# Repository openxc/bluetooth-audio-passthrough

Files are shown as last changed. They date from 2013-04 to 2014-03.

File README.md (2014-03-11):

Bluetooth Audio Accessory
=========================

This repository is a part of the [OpenXC][] project.

This repository contains the documentation and open source design files for an
example OpenXC hardware accessory, the Bluetooth Audio accessory, originally
created by Ford.

There is a [gallery of
photos](https://plus.google.com/photos/108408483770573977605/albums/5989364910333751905)
of the prototype accessory.

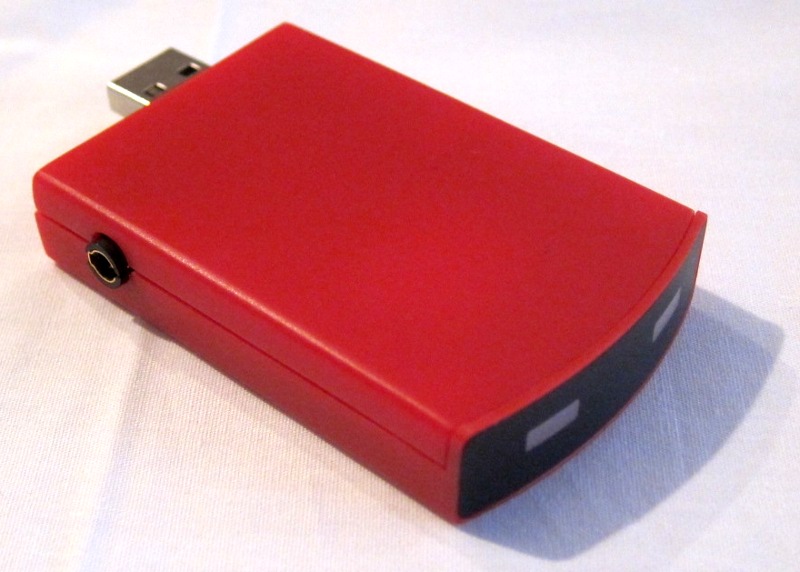
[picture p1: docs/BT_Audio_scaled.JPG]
Bluetooth Audio Accessory The Bluetooth Audio Accessory


### Description

The Bluetooth Audio Passthrough is an audio-capable Bluetooth chipset, powered
and configurable over USB. The Passthrough uses a Bluegiga WT-32 Bluetooth
module, which is capable of running several different Bluetooth profiles in the
Bluetooth 2.1 standard (and even multiple profiles in parallel). By default, the
BT Passthrough will appear as an A2DP audio sink - an audio endpoint that can
wirelessly stream audio from a cellphone music player to a car Aux input.

### Features

* Supports many Bluetooth protocols out of the box: SPP, DUN, OBEX OPP, HFP
    (v.1.5) A2DP, AVRCP, DID and HID
* Configurable over USB using easy-to-read commands
* 2 output channels (stereo), one input channel (mono)
* Provides a 2.7v microphone bias
* Output headphone amplifier capable of driving up to 105mW per channel

Documents
---------

The schematics, board layout, BOM and testing results are in the `schematics`
directory of this repository.

The schematics were created with Eagle, and are also available as PNGs.

### Assembly Files

The assembly files are in the `fabrication` subfolder, including the board
layout DXF and and archive of all assembly files:

 * .top  - Top Copper Layer
 * .bot  - Bottom Copper Layer
 * .smt - Top Soldermask
 * .slk - Top Silkscreen
 * .tsp - Top Solderpaste
 * .smb - Bottom Soldermask
 * .bsk - Bottom Silkscreen
 * .bsp - Bottom Solderpaste
 * .oln - PCB Outline
 * .drd - Excellon Drill Data
 * .drl - Basic Drill tool information
 * .dri - Extended Drill tool information

Details
-------

### Block diagram

Bluetooth Audio Block Diagram

### Parts Layout

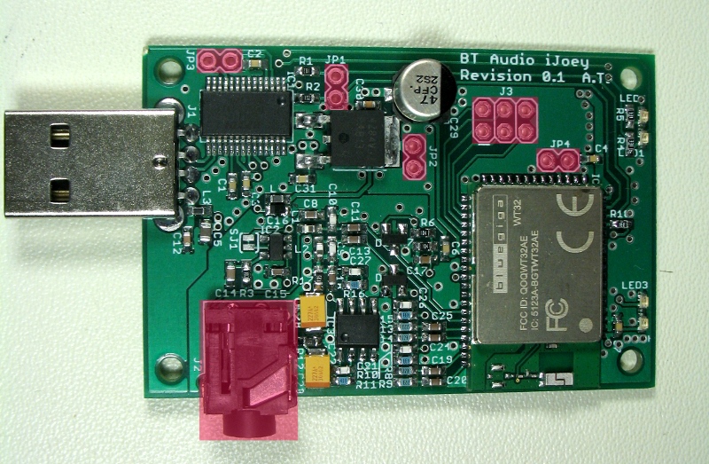
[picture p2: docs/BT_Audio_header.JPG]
Bluetooth Audio Headers


### Inputs/Outputs

* JP1 - Serial RX and TX lines - if the USB-Serial interface is not working,
    the TX and RX serial lines can be accessed from this header.
* JP2 - Power - Access to the +3.3V and Ground power rails.
* JP3 - USB CTS and RTS - Access to the hardware flow control lines provided
    by the FT232RL USB to serial IC.
* JP4 - Bluetooth CTS and RTS - Access to the hardware flow control lines on
    the WT32 adapter. Can be used with JP3 to enable hardware flow control.
* J3 - SPI programming interface - If the firmware on the WT32 needs to be
    updated from iWrap 4, this interface can be used.
* J2 (the Headphone Jack) - This is a 4 pole TRRS connector, which can be used
    for 2 output channels and 1 input channel. A standard 3-pin TRS headphone
    cable can be used, and the microphone input will be unused.
    * Pin 1 (tip) - Out Left
    * Pin 2 (ring 1) - Out Right
    * Pin 3 (ring 2) - Ground
    * Pin 4 (shield) - Microphone Input

Usage:
------

### How to use

1. Plug the Bluetooth Audio Accessory into the Dock
1. Connect the short 4-pin 1/8" TRRS cable to the audio jack on the Accessory
1. Connect the other end of the TRRS cable into the dock
1. Plug a 1/8" headset or 1/8" extension cable into the dock
1. On a smartphone or tablet, search for Bluetooth devices
1.  A "WT-32" device should appear. Pair with it. No PIN code should be
    necessary, but "0000" can be used.
1.  Once pairing is complete, connect to the WT-32 device
1. The LED on the Bluetooth Audio Accessory should turn green and the Bluetooth
    host should now play audio through the device.

### How to program

Upon receiving a Bluetooth Audio Accessory from the factory, a quick
configuration step will be required:

1. Connect the Accessory directly into the USB port of a PC
1. The accessory should appear as a serial device (/dev/ttyUSBX in linux, COMX
   in windows, /dev/tty.usbserial-xxxxxxxx in OSX).
1. In a terminal application, open the serial port with baud 115200 and no
   hardware flow control.
1. Type ```RESET``` and press enter. The Accessory should respond with the
   iWrap firmware version.
1. Type the following commands, pressing enter after each line:

```
SET BT SSP 3 0
SET BT AUTH * 0000
SET PROFILE A2DP SINK
SET PROFILE AVRCP CONTROLLER
SET BT CLASS 240438
SET CONTROL GAIN D D
SET CONTROL INIT SET CONTROL GAIN D D
SET CONTROL CD 400 0
RESET
```

The device should now be ready for use as an A2DP sink. Here are a few other
popular protocols (repeat the above steps to apply):

#### A2DP Sink (Audio from Bluetooth to Speaker)

```
SET PROFILE A2DP SINK

SET PROFILE AVRCP CONTROLLER

SET BT CLASS 240438
```

#### A2DP Source (Audio from Microphone to Bluetooth)

```
SET PROFILE A2DP SOURCE

SET PROFILE AVRCP TARGET

SET BT CLASS 280428
```

#### HFP - Hands Free Protocol (Act like Bluetooth Headset)

```
SET BT SSP 3 0
SET BT AUTH * 0000
SET PROFILE HFP ON
SET BT CLASS 200404
```

### Known issues

#### v0.1

* Audio output noise
    * Power supply - The audio output is fairly sensitive to power supply
        noise. The +5V USB power supply is filtered, but very noisy USB busses
        can still produce audible pops and buzzes
    * Bluetooth - The headphone amplifier is somewhat sensitive to Bluetooth
        energy. If the connected tablet or cell phone is held very closely to
        the BT Passthrough, cellular and/or Bluetooth noise will be induced into the
        audio output. Try not to rest any cellular devices immediately against
        the Passthrough.
* Audio output level - The default gain on the WT32 chipset is fairly
    conservative. To increase the default gain, connect the BT Passthrough to a PC. It
    should appear as a serial device. Connect to that serial device at 115200
    baud, and send the following commands:

```
RESET

SET CONTROL GAIN D D

SET CONTROL INIT SET CONTROL GAIN D D

RESET
```

Try adjusting the 0xD parameter above (valid range is 0 - 17 in hexadecimal, see
the WT-32 manual). In testing, a gain of 0xD is the highest that a pair of 64
ohm headphones would tolerate before distortion.

Design details:
---------------

### Bluetooth Chipset

The WT-32 was selected as a prototype-friendly Bluetooth Audio chipset. It was
the only chipset available from distributors like SparkFun that had full, native
audio support. Advantages:

* Simple serial command protocol
* Many built-in Bluetooth protocols
* Built-in microphone pre-amplifier with software-adjustable gain
* software-adjustable output gain as well

The basic WT-32 design is very strongly based from its [Evaluation
Board](http://www.digikey.com/product-search/en/rf-if-and-rfid/rf-evaluation-and-development-kits-boards/3539644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).
The WT32 documentation is available in the Documentation directory.

### Configuration Interface

The WT-32 is configured by a serial UART at 115200 baud. This is exposed via
USB using an industry-standard [FTDI
FT232RL](http://www.ftdichip.com/Support/Documents/DataSheets/ICs/DS_FT232R.pdf)
USB to serial converter IC. The chip requires few external components - each
power rail is decoupled with 0.1uF capacitors, TX and RX LEDs are included, and
the UART is protected from excess current through RX and TX resistors R1 and R2.
USB signals require high speed PCB routing to avoid signal integrity issues,
since the bitrates are high (11Mbps - 480Mbps). Unfortunately with a 2 layer
PCB, the trace widths required to obtain the ideal 90 ohm differential impedance
for a USB line would be unfeasibly wide. To compensate for this fact, the USB
connector was located extremely close (~300 mils) to the FTDI 232RL USB pins.

The WT-32 also has an ICSP header if future firmware updates are desired.
Current WT-32 modules will ship with either iWrap4 or iWrap5 firmware, both of
which contain the necessary configurations and protocols needed by the
accessory. Upgrading shouldn't be necessary, but is possible using the SPI bus
exposed by J3. See the WT32 documentation for firmware upgrade procedures.

### Power

A single Low Dropout linear regulator is used to step the +5V USB power down to
the 3.3V required by the Bluetooth module. IC5 preforms this task, providing up
to 1.6A of current (far more than is necessary). The power is filtered in two
places. Immediately after entering via the USB connector, power is passed
through inductor L3 with filtering capacitors C12 and C5. This is from the
FT232RL reference design. An additional filtering stage separates the normal
+3.3V rail from the +3.3V used by the analog audio circuitry. Analog power is
run through inductor L4 and decoupled by C16 in an attempt to remove additional
transients caused by the power draw of the WT32.

A DC midpoint is also required by the output amplifier. Since the amplifier is
a single-ended device (no negative power rail is available), a midpoint is
required to properly bias / center the audio signal before amplification. This
is generated using a rudimentary resistor divider of R6 and R7. Excess DC
midpoint current can unbalance the amplifier, but with the low input impedance
of the output amplifier, this shouldn't be an issue. If the DC midpoint becomes
unbalanced, or if more ground filtering is desired, consider buffering the
DC_MID signal with an opamp.

### Analog Microphone Input

The microphone input receives it's signal from pin 4 of the TRRS audio
connector. IC2 provides a 2.7V microphone bias for the microphone in a
connected headset. The WT32 contains a microphone bias output, but the
reference schematic recommends using an additional Low Dropout Regulator (IC2)
instead. The LDO provides additional power filtering for the microphone bias,
which is an extremely noise-sensitive signal for an electret microphone element.
This circuit assumes a microphone element with an impedance in the 1k - 3k range
(specifically we are matching 1K using resistor R3).

Inductors L1 and L2 and capacitors C9 and C10 attempt to filter excess high
frequency noise from the microphone. Capacitors C11 and C13 decouple the
microphone signal before connecting it to the WT32. Diodes D1 and D2 protect
the WT-32 built-in microphone preamplifier and ADC from damage due to voltage
transients by clamping the microphone signal to +3.3v and Ground. Note that
this circuit uses a shared ground for the microphone input and the headphone
output - if crosstalk between headphones and microphone becomes an issue,
consider spliting the 4-pin TRRS jack into two seperate 3-pin TRS jacks.

### Headphone / Line output

A [TI LM4808 Headphone Amplifier](http://www.ti.com/lit/ds/symlink/lm4808.pdf)
isolates the audio output from the WT32. The reference design was pulled
directly from the WT-32 evaluation board. The amplifier also converts the
differential audio output of the WT32 into a single-ended output used by most
headphones and consumer electronics. Note that output decoupling capacitors C23
and C28 are specified as Tantalum capacitors, since they lie directly in the
audio pathway and need to be robust to handle the voltage transients of plugging
and unplugging audio signals. Care must be taken to chose capacitors with a
good sonic signature, low ESR and a sufficient voltage rating.

## License

Copyright (c) 2014 Ford Motor Company

The electrical and mechanical designs in this repository are available under the
[Creative Commons Attribution 4.0
International](http://creativecommons.org/licenses/by/4.0/deed.en_US) license.

[OpenXC]: http://openxcplatform.com

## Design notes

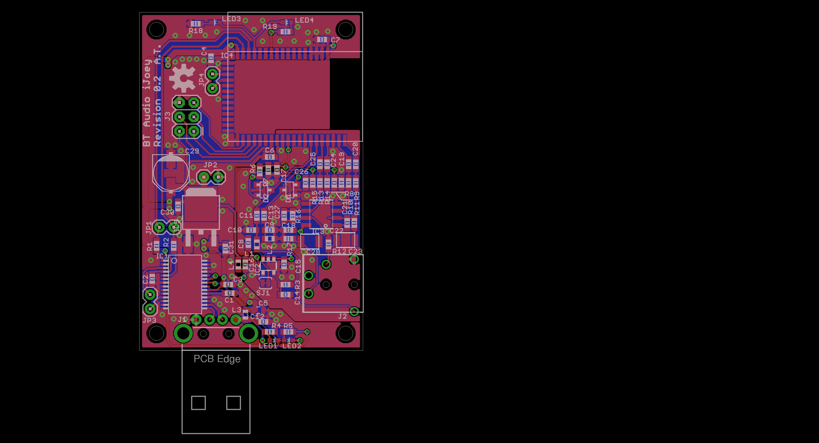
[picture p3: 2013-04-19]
schematics/BT_Audio_iJoey.brd.png

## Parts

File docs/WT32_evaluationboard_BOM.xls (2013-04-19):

WT32 Evaluation Kit
BOM ver. 2.6, 31.03.2011
Bluegiga Technologies Oy
Author: Pra
Item | Qty | Reference | Value | Description | ROHS PN=Orderable PN | Distributor | Distributor PN | Mounted | Manufacturer | Second source | Second source PN | Package
1 | 4 | DIO1-4 |  | Schottky diode | BAT54S |  |  | TRUE | FAIRCHILD
2 | 6 | SW4 SW6-10 |  | Switch button | KSC423J |  |  | TRUE | C & K
3 | 20 | C14-20 C23-24 C40-46 C51-54 | 0.1uF/25V/X7R | General Ceramic Chip Capacitor | GRM188R71E104KA01 | Elgood |  | TRUE | Murata |  |  | 603
4 | 4 | C25 C50 C55-56 | 0.22uF/6.3V/X5R | General Ceramic Chip Capacitor | GRM155R60J224KE01 | Elgood |  | TRUE | Murata |  |  | 402
5 | 1 | C29 | 1000pF/50V/X7R | General Ceramic Chip Capacitor | GRM155R71H102KA01 | Elgood |  | TRUE | Murata |  |  | 402
6 | 1 | C10 | 10uF/6.3V/Y5V | Monolithic Ceramic Chip Capacitor | GRM21BF50J106ZE01K | Elgood |  | TRUE | Murata |  |  | 805
7 | 1 | C28 | 10uF/16V/10%/TAN | Tantalum Capacitor | T491A106K016AT | Arrow/Farnell | 1310077 | TRUE | Kemet |  |  | CASE-A
8 | 1 | C49 | NP | General Ceramic Chip Capacitor | NP |  |  | FALSE
9 | 6 | C5-8 C11 C48 | 15pF/50V/C0G | High Q Low ESR Ceramic Chip Capacitor | GJM1555C1H150JB01 | Elgood |  | TRUE | Murata |  |  | 402
10 | 12 | C1-4 C9 C26-27 C30-33 C38 | 1uF/16V/X5R | General Ceramic Chip Capacitor | GRM188R61C105KA93 | Elgood |  | TRUE | Murata |  |  | 603
11 | 2 | C12-13 | 220uF/10V/10%/TAN | Tantalum Capacitor | T491D227K010AT | Arrow/Farnell | 1310127 | TRUE | Kemet |  |  | CASE-D
12 | 1 | C22 | 22uF/16V/10%/TAN | Tantalum Capacitor | T491B226K016AT | Arrow/Farnell | 1308258 | TRUE | Kemet |  |  | CASE-B
13 | 2 | C21 C39 | 2.2uF/10V/X5R | General Ceramic Chip Capacitor | GRM188R61A225KE34 | Elgood |  | TRUE | Murata
14 | 4 | C34-37 | 33pF/50V/C0G | General Ceramic Chip Capacitor | GRM1555C1H330JZ01 | Elgood |  | TRUE | Murata
15 | 1 | C47 | 4u7 | General Ceramic Chip Capacitor | GRM188R60J475KE19 | Elgood |  | TRUE | Murata |  |  | 603
16 | 1 | J10 |  | Mini-USB connector, socket, SMD | 2486 01 | Farnell | 1243250 | TRUE | Lumberg
17 | 3 | FID1-3 | Fiducial Mark 1mm , 2mm keep out | Fiducial Mark 1mm , 2mm keep out | N/A | N/A | N/A | FALSE | N/A | N/A | N/A
18 | 3 | J11-13 |  | TWO PIN INLINE HEADER; 100 MIL CENTERS | 826936-2 |  |  | TRUE | TYCO Electronics
19 | 1 | J9 |  | Header, smd, 2x3 pin, 100 mil | 146134-2 |  |  | TRUE | AMP
20 | 1 | J17 | HEADER, 8PIN | Header, 8 pin, SMD, 2.54mm, dual row | TSM-104-01-F-DV | Q-Flex |  | TRUE | Samtec | Any | Any
21 | 1 | J3 | 53047-0210 | Battery connector | 53047-0210 |  |  | TRUE | MOLEX
22 | 1 | J1 |  | Header, 2x12, SMD, 100 mil | 1-1241050-2 | FARNELL | 9689630 | TRUE | TYCO/AMP
23 | 2 | D2-3 | HSMC-C190 | LED, SMD, Red | HSMC-C190 | Farnell | 8554510 | TRUE | Avago Technologies |  |  | HSMX-C190
24 | 1 | D1 |  | HSMG-C190 | HSMG-C190 |  |  | TRUE | Agilent Technologies
25 | 1 | L6 | 10µH±10%, 225mA, 1.2ohm | Chip Coil for DC-DC Converter Wire Wound Type | LQH2MCN100K02L | Elgood |  | TRUE | Murata
26 | 4 | L1-4 | 15nH+/-2%, 90mA, 1.8ohm | Chip Coil for High Frequency, Film Type | LQP15MN15NG02 | Elgood |  | TRUE | Murata |  |  | 402
27 | 1 | U4 | LM4808MM | Audio PA | LM4808MM |  |  | TRUE | National |  |  | MiniSO
28 | 3 | J6-8 |  | MX-387GL | MX-387GL | Tele-Tukku Oy |  | TRUE | MARUSHIN ELECTRIC
29 | 1 | U7 | NC7SZ14P5X_NL | Inverter gate | NC7SZ14P5X_NL |  |  | TRUE | FAIRCHILD SEMICONDUCTOR
30 | 1 | U13 |  | Mini logic OR gate | NC7SZ32M5 |  |  | TRUE | FAIRCHILD SEMICONDUCTOR
31 | 2 | U6 U9 |  | NC7SZ125M5 | NC7SZ125M5 |  |  | TRUE | FAIRCHILD SEMICONDUCTOR
32 | 4 | R2 R36 R38 R43 | 0R0, 50V, 2.0A, 0.2W | General Purpose Chip Resistor | 232270591001L | Arrow |  | TRUE | PHYCOMP | Tyco | CRG0402F0R0
33 | 4 | R52-53 R56-57 | 0R0, 50V, 2.0A, 0.2W | General Purpose Chip Resistor | 232270591001L | Arrow |  | FALSE | PHYCOMP | Tyco | CRG0402F0R0
34 | 2 | R24-25 | 470R, 50V, 0.063W | General Purpose Chip Resistor |  |  |  | TRUE |  |  |  | 402
35 | 5 | R26-29 R31 | 10K, 50V, 0.063W | General purpose chip resistor | 2322 7067 1003 L |  |  | TRUE | PHYCOMP |  |  | 402
36 | 8 | R44-51 | 10K, 50V, 0.063W | General Purpose Chip Resistor | 232270671003L | Arrow |  | TRUE | PHYCOMP | Tyco | CRG0402F10K
37 | 2 | R10 R35 | 120R, 50V, 0.063W | General Purpose Chip Resistor | 232270671201L | Arrow |  | TRUE | PHYCOMP | Tyco | CRG0402F120R | 402
38 | 3 | R1 R33 R41 | 1K | cer.smd | 2322 7067 1002 L | Arrow |  | TRUE | PHYCOMP | Tyco | CRG0402F0R0 | 402
39 | 3 | R6-7 R14 | 1M, 50V, 0.063W | General Purpose Chip Resistor | 232270671005L | Arrow |  | TRUE | PHYCOMP | Tyco | CRG0402F1M | 402
40 | 4 | R16-19 | 22K, 50V, 0.063W | General Purpose Chip Resistor | 232270672203L | Arrow |  | TRUE | PHYCOMP | Tyco | CRG0402F22K
41 | 2 | R8-9 | 39R, 50V, 0.063W | General Purpose Chip Resistor | 232270673909L | Arrow |  | TRUE | PHYCOMP | Tyco | CRG0402F39R
42 | 1 | R11 | 3K, 50V, 0.063W | General Purpose Chip Resistor | 232270673002L | Arrow |  | TRUE | PHYCOMP | Tyco | CRG0402F3K | 402
43 | 4 | R20-23 | 43K, 50V, 0.063W | General Purpose Chip Resistor | 232270674303L | Arrow |  | TRUE | PHYCOMP | Tyco | CRG0402F43K
44 | 3 | R13 R30 R39 | 510R, 50V, 0.063W | General Purpose Chip Resistor | 232270675101L | Arrow |  | TRUE | PHYCOMP | Tyco | CRG0402F510R | 402
45 | 1 | R12 | 5.1K, 50V, 0.063W | General Purpose Chip Resistor | 232270675102L | Arrow |  | TRUE | PHYCOMP | Tyco | CRG0402F5K1 | 402
46 | 4 | R3-4 R54-55 | 7.5K, 50V, 0.063W | General Purpose Chip Resistor | 232270677502L | Arrow |  | TRUE | PHYCOMP | Tyco | CRG0402F7K5 | 402
47 | 1 | R15 | 820K, 50V, 0.063W | General Purpose Chip Resistor | 232270678204L | Arrow |  | TRUE | PHYCOMP | Tyco | CRG0402F820K | 402
48 | 7 | R5 R32 R34 R37 R40 R59-60 | NP |  |  |  |  | FALSE
49 | 1 | R42 | NP | General Purpose Chip Resistor | 232270591001L | Arrow |  | FALSE | PHYCOMP | Tyco | CRG0402F0R0
50 | 1 | J5 |  | RS232 CONNECTOR, 9 PIN, MALE | 5747840-4 |  |  | TRUE | TYCO
51 | 3 | J14-16 |  | Shorting link, 100 mil | 2,54MKB |  |  | TRUE | LUMBERG
52 | 3 | SW11-13 |  | Switch, SPDT | SLS121PCFN |  |  | TRUE | TYCO Electronics
53 | 2 | U1 U5 |  | RS232 driver | MAX3222ECAP |  |  | TRUE | MAXIM |  |  | SSOP20
54 | 1 | SW14 | MMS228T | Slide switch, smd | MMS228T | Farnell | 8546819 | TRUE | Knitter Switch
55 | 2 | SW1-2 | MMS238T | Slide switch, smd | MMS238T | Farnell | 8546827 | TRUE | Knitter Switch
56 | 2 | U10-11 | TPA6205A1DGN | Fully differential audio PA | TPA6205A1DGN | Farnell | 1533693 | TRUE | Texas Instruments |  |  | MSOP-8
57 | 1 | U3 |  | Low quiescent current, low noise linear regulator | TPS79933DDCT |  |  | TRUE | TEXAS INSTRUMENTS
58 | 1 | U2 | USBLC6-2SC6 | Very Low Capacitance ESD Protection | USBLC6-2SC6 | Farnell | 1269406 | TRUE | STM
59 | 1 | MOD1 |  |  |  |  |  | TRUE
60 | 1 | U8 | XC6204B272MR | Low quiescent current, low noise linear regulator | XC6204B272MR |  |  | TRUE | TOREX
 |  |  | NP means MOUNTED=FALSE

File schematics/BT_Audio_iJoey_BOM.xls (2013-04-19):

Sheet: BOM
Part | Value | Package | Placement important | Manu | Part # | Volt/Precision | Other | Link | Cost/1k | Notes
C1 | 0.1u | 0603-CAP |  | Kemet | C0603C104K4RACTU | X7R | 16V | http://ca.mouser.com/ProductDetail/Kemet/C0603C104K4RACTU/ | 0.005
C2 | 0.1u | 0603-CAP |  | Kemet | C0603C104K4RACTU | X7R | 16V | http://ca.mouser.com/ProductDetail/Kemet/C0603C104K4RACTU/ | 0.005
C3 | 0.1u | 0603-CAP |  | Kemet | C0603C104K4RACTU | X7R | 16V | http://ca.mouser.com/ProductDetail/Kemet/C0603C104K4RACTU/ | 0.005
C4 | 0.1u | 0603-CAP |  | Kemet | C0603C104K4RACTU | X7R | 16V | http://ca.mouser.com/ProductDetail/Kemet/C0603C104K4RACTU/ | 0.005
C5 | 10u | 0805 |  | Kemet | C0805C106K4PACTU | X5R | 16V | http://ca.mouser.com/ProductDetail/Kemet/C0805C106K4PACTU/ | 0.071
C6 | 0.1u | 0603-CAP |  | Kemet | C0603C104K4RACTU | X7R | 16V | http://ca.mouser.com/ProductDetail/Kemet/C0603C104K4RACTU/ | 0.005
C7 | 0.1u | 0603-CAP |  | Kemet | C0603C104K4RACTU | X7R | 16V | http://ca.mouser.com/ProductDetail/Kemet/C0603C104K4RACTU/ | 0.005
C8 | 1u | 0603-CAP |  | TDK | C1608X7R1C105K | X7R | 16V | http://ca.mouser.com/ProductDetail/TDK/C1608X7R1C105K/?qs=sGAEpiMZZMvQvaS66kI3Tk6Pvfi1sRGOjhNuqGh8w0I%3d | 0.019
C9 | 15p | 0603-CAP |  | Kemet | C0603C150J5GACTU | C0G | 50V | http://ca.mouser.com/ProductDetail/Kemet/C0603C150J5GACTU/ | 0.01
C10 | 15p | 0603-CAP |  | Kemet | C0603C150J5GACTU | C0G | 50V | http://ca.mouser.com/ProductDetail/Kemet/C0603C150J5GACTU/ | 0.01
C11 | 1u | 0603-CAP |  | TDK | C1608X7R1C105K | X7R | 16V | http://ca.mouser.com/ProductDetail/TDK/C1608X7R1C105K/?qs=sGAEpiMZZMvQvaS66kI3Tk6Pvfi1sRGOjhNuqGh8w0I%3d | 0.019
C12 | 10n | 0603-CAP |  | TDK | CGJ3E2X7R1H103K | X7R | 50V | http://ca.mouser.com/ProductDetail/TDK/CGJ3E2X7R1H103K/ | 0.012
C13 | 1u | 0603-CAP |  | TDK | C1608X7R1C105K | X7R | 16V | http://ca.mouser.com/ProductDetail/TDK/C1608X7R1C105K/?qs=sGAEpiMZZMvQvaS66kI3Tk6Pvfi1sRGOjhNuqGh8w0I%3d | 0.019
C14 | 4.7u | 0603-CAP |  | TDK | C1608X6S1C475K | X6S | 16V | http://ca.mouser.com/ProductDetail/TDK/C1608X6S1C475K/ | 0.117
C15 | 1u | 0603-CAP |  | TDK | C1608X7R1C105K | X7R | 16V | http://ca.mouser.com/ProductDetail/TDK/C1608X7R1C105K/?qs=sGAEpiMZZMvQvaS66kI3Tk6Pvfi1sRGOjhNuqGh8w0I%3d | 0.019
C16 | 10u | 0603-CAP |  | Nichicon | F981A106MMA | 20.00% | 10V | http://ca.mouser.com/ProductDetail/Nichicon/F981A106MMA/ | 0.371 | Tantalum capacitor for analog power quality
C17 | 2.2u | 0603-CAP |  | TDK | C1608Y5V1C225Z | Y5V | 16V | http://ca.mouser.com/ProductDetail/TDK/C1608Y5V1C225Z/ | 0.021
C18 | 1u | 0603-CAP |  | TDK | C1608X7R1C105K | X7R | 16V | http://ca.mouser.com/ProductDetail/TDK/C1608X7R1C105K/?qs=sGAEpiMZZMvQvaS66kI3Tk6Pvfi1sRGOjhNuqGh8w0I%3d | 0.019
C19 | 1u | 0603-CAP |  | TDK | C1608X7R1C105K | X7R | 16V | http://ca.mouser.com/ProductDetail/TDK/C1608X7R1C105K/?qs=sGAEpiMZZMvQvaS66kI3Tk6Pvfi1sRGOjhNuqGh8w0I%3d | 0.019
C20 | 1u | 0603-CAP |  | TDK | C1608X7R1C105K | X7R | 16V | http://ca.mouser.com/ProductDetail/TDK/C1608X7R1C105K/?qs=sGAEpiMZZMvQvaS66kI3Tk6Pvfi1sRGOjhNuqGh8w0I%3d | 0.019
C21 | 33p | 0603-CAP |  | Kemet | C0603C330J5GAC7411 | C0G | 50V | http://ca.mouser.com/ProductDetail/Kemet/C0603C330J5GAC7411/?qs=sGAEpiMZZMvQvaS66kI3TnRV7jmGngRVERJ7QEpwH6c%3d | 0.012
C22 | 33p | 0603-CAP |  | Kemet | C0603C330J5GAC7411 | C0G | 50V | http://ca.mouser.com/ProductDetail/Kemet/C0603C330J5GAC7411/?qs=sGAEpiMZZMvQvaS66kI3TnRV7jmGngRVERJ7QEpwH6c%3d | 0.012
C23 | 220u | 1210 |  | Kemet | TLJB227M006R0500 | 20.00% | 6.3V | http://ca.mouser.com/ProductDetail/AVX/TLJB227M006R0500/ | 1.46 | High cost due to size, larger alternative: T491C227M010ZT
C24 | 1u | 0603-CAP |  | TDK | C1608X7R1C105K | X7R | 16V | http://ca.mouser.com/ProductDetail/TDK/C1608X7R1C105K/?qs=sGAEpiMZZMvQvaS66kI3Tk6Pvfi1sRGOjhNuqGh8w0I%3d | 0.019
C25 | 1u | 0603-CAP |  | TDK | C1608X7R1C105K | X7R | 16V | http://ca.mouser.com/ProductDetail/TDK/C1608X7R1C105K/?qs=sGAEpiMZZMvQvaS66kI3Tk6Pvfi1sRGOjhNuqGh8w0I%3d | 0.019
C26 | 33p | 0603-CAP |  | Kemet | C0603C330J5GAC7411 | C0G | 50V | http://ca.mouser.com/ProductDetail/Kemet/C0603C330J5GAC7411/?qs=sGAEpiMZZMvQvaS66kI3TnRV7jmGngRVERJ7QEpwH6c%3d | 0.012
C27 | 33p | 0603-CAP |  | Kemet | C0603C330J5GAC7411 | C0G | 50V | http://ca.mouser.com/ProductDetail/Kemet/C0603C330J5GAC7411/?qs=sGAEpiMZZMvQvaS66kI3TnRV7jmGngRVERJ7QEpwH6c%3d | 0.012
C28 | 220u | 1210 |  | Kemet | TLJB227M006R0500 | 20.00% | 6.3V | http://ca.mouser.com/ProductDetail/AVX/TLJB227M006R0500/ | 1.46 | High cost due to size, larger alternative: T491C227M010ZT
C29 | 47u | PANASONIC_D | YES | Panasonic | EEE-FP1C470AP | 16V | ESR 0.26 | http://ca.mouser.com/ProductDetail/Panasonic-Electronic-Components/EEE-FP1C470AP/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 | 0.143
C30 | 22n | 0603-CAP |  | Kemet | C0603C223K5RACTU | X7R | 50V | http://ca.mouser.com/ProductDetail/Kemet/C0603C223K5RACTU/ | 0.012
C31 | 0.1 | 0603-CAP |  | Kemet | C0603C104K4RACTU | X7R | 16V | http://ca.mouser.com/ProductDetail/Kemet/C0603C104K4RACTU/ | 0.005
D1 | BAT54S | SOT23 |  | Fairchild | BAT54S | 30V | 0.6A | http://ca.mouser.com/ProductDetail/Fairchild-Semiconductor/BAT54S/ | 0.032
D2 | BAT54S | SOT23 |  | Fairchild | BAT54S | 30V | 0.6A | http://ca.mouser.com/ProductDetail/Fairchild-Semiconductor/BAT54S/ | 0.032
IC1 | FT232RLSSOP | SSOP28DB |  | FTDI | FT232RL-REEL | 5.25V |  | http://ca.mouser.com/ProductDetail/FTDI/FT232RL-REEL/ | 2.84
IC2 | LP2981 | SOT23-5 |  | TI | TPS73028DBVT | 2.8v | 200mA | http://ca.mouser.com/ProductDetail/Texas-Instruments/TPS73028DBVT/ | 0.416
IC3 | LM4808MM | SO8 |  | TI | LM4808M/NOPB | 5.5v | 150mW | http://www.digikey.com/product-detail/en/LM4808M%2FNOPB/LM4808M%2FNOPB-ND/364157 | 0.336
IC4 | WT32 | WT32 |  | Bluegiga | WT32-A-AI4 | 3.3v |  | http://ca.mouser.com/ProductDetail/Bluegiga-Technologies/WT32-A-AI4/ | 25.68 | WT32-A-AI5 should be a valid upgrade once stock is available
IC5 | TLE4284DV33 | V-REG_DPACK |  | Infineon | TLE4284D V33 | 3.3V | 1A | http://www.digikey.ca/product-detail/en/TLE4284D%20V33/TLE4284D%20V33TR-ND/1016100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 | 1.025
J1 | USB-A-H | USB-A-H | YES | Samtec | USB-AM-S-F-B-TH | 1A |  | http://components.arrow.com/part/detail/43114295S7160411N1004?region=na | 0.8266 | Any USB-AM-S will do, sparkfun part # PRT-00437 also valid
J2 | AUDIO-JACK-4PSWSJ-43515 | SJ-4351X | YES | CUI Inc | SJ-43514 |  | 4 Conductor | http://www.digikey.com/product-detail/en/SJ-43514/CP-43514-ND/368146 | 0.552
J3 | ICSP | 2X3 | YES |  | DNP |  |  | http://www.te.com/catalog/pn/en/826632-3 |  | DO NOT POPULATE, Leave room within enclosure if possible
JP1 | M02PTH | SparkFun-Connectors |  |  | DNP |  |  |  |  | DO NOT POPULATE, added for FTDI debug
JP2 | M02PTH | SparkFun-Connectors |  |  | DNP |  |  |  |  | DO NOT POPULATE, added for FTDI debug
JP3 | M02PTH | SparkFun-Connectors |  |  | DNP |  |  |  |  | DO NOT POPULATE, added for FTDI debug
JP4 | M02PTH | SparkFun-Connectors |  |  | DNP |  |  |  |  | DO NOT POPULATE, added for FTDI debug
L1 | 15n | 603 |  | Taiyo Yuden | HK160815NJ-T | 0.3nH | 0.3A | http://ca.mouser.com/ProductDetail/Taiyo-Yuden/HK160815NJ-T/ | 0.039
L2 | 15n | 603 |  | Taiyo Yuden | HK160815NJ-T | 0.3nH | 0.3A | http://ca.mouser.com/ProductDetail/Taiyo-Yuden/HK160815NJ-T/ | 0.039
L3 | BK0603HS330 | 603 |  | Taiyo Yuden | BKP1608HS330-T | 25.00% | 3A | http://ca.mouser.com/ProductDetail/Taiyo-Yuden/BKP1608HS330-T/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 | 0.042
L4 | 10u | 603 |  | TDK | MLZ1608N100L | 20.00% | 300mA | http://ca.mouser.com/ProductDetail/TDK/MLZ1608N100L/ | 0.059
LED1 | TX | LED-0603 | YES | Kingbright | APA1606SURCK | 1.95v | 20mA | http://ca.mouser.com/ProductDetail/Kingbright/APA1606SURCK/?qs=sGAEpiMZZMtEjy7lsqBi5QZiKsKozmc0xPh23Fre9Nk%3d | 0.077 | Red
LED2 | RX | LED-0603 | YES | Kingbright | APA1606SGC | 2.2v | 20mA | http://ca.mouser.com/ProductDetail/Kingbright/APA1606SGC/ | 0.096 | Green
LED3 | CONN | LED-0603 | YES | Kingbright | APA1606SGC | 2.2v | 20mA | http://ca.mouser.com/ProductDetail/Kingbright/APA1606SGC/ | 0.096 | Green
LED4 | PWR | LED-0603 | YES | Kingbright | APA1606SURCK | 1.95v | 20mA | http://ca.mouser.com/ProductDetail/Kingbright/APA1606SURCK/?qs=sGAEpiMZZMtEjy7lsqBi5QZiKsKozmc0xPh23Fre9Nk%3d | 0.077 | Red
R1 | 1k | 0603-RES |  | KOA Speer | RK73B1JTTD102J | 5.00% | 100mW | http://ca.mouser.com/ProductDetail/KOA-Speer/RK73B1JTTD102J/ | 0.018
R2 | 1k | 0603-RES |  | KOA Speer | RK73B1JTTD102J | 5.00% | 100mW | http://ca.mouser.com/ProductDetail/KOA-Speer/RK73B1JTTD102J/ | 0.018
R3 | 1k | 0603-RES |  | KOA Speer | RK73B1JTTD102J | 5.00% | 100mW | http://ca.mouser.com/ProductDetail/KOA-Speer/RK73B1JTTD102J/ | 0.018
R4 | 120 | 0603-RES |  | KOA Speer | RK73B1JTTD121J | 5.00% | 100mW | http://ca.mouser.com/ProductDetail/KOA-Speer/RK73B1JTTD121J/ | 0.018
R5 | 330 | 0603-RES |  | KOA Speer | RK73B1JTTDD331J | 5.00% | 100mW | http://ca.mouser.com/ProductDetail/KOA-Speer/RK73B1JTTDD331J/ | 0.018
R6 | 100k | 0603-RES |  | KOA Speer | RK73B1JTTD104J | 5.00% | 100mW | http://ca.mouser.com/ProductDetail/KOA-Speer/RK73B1JTTD104J/?qs=sGAEpiMZZMvdGkrng054t1eDf6HruEFgwpPTqQd3kEE%3d | 0.018
R7 | 100k | 0603-RES |  | KOA Speer | RK73B1JTTD104J | 5.00% | 100mW | http://ca.mouser.com/ProductDetail/KOA-Speer/RK73B1JTTD104J/?qs=sGAEpiMZZMvdGkrng054t1eDf6HruEFgwpPTqQd3kEE%3d | 0.018
R8 | 22k | 0603-RES |  | KOA Speer | RK73H1JTTD2202F | 1.00% | 100mW | http://ca.mouser.com/ProductDetail/KOA-Speer/RK73H1JTTD2202F/ | 0.016
R9 | 22k | 0603-RES |  | KOA Speer | RK73H1JTTD2202F | 1.00% | 100mW | http://ca.mouser.com/ProductDetail/KOA-Speer/RK73H1JTTD2202F/ | 0.016
R10 | 43K | 0603-RES |  | KOA Speer | RK73H1JTTD4302F | 1.00% | 100mW | http://ca.mouser.com/ProductDetail/KOA-Speer/RK73H1JTTD4302F/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 | 0.016
R11 | 43K | 0603-RES |  | KOA Speer | RK73H1JTTD4302F | 1.00% | 100mW | http://ca.mouser.com/ProductDetail/KOA-Speer/RK73H1JTTD4302F/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 | 0.016
R12 | 1M | 0603-RES |  | KOA Speer | RK73B1JTTD105J | 5.00% | 100mW | http://ca.mouser.com/ProductDetail/KOA-Speer/RK73B1JTTD105J/?qs=sGAEpiMZZMvdGkrng054t1eDf6HruEFgk7tZ8JYmT6o%3d | 0.018
R13 | 22k | 0603-RES |  | KOA Speer | RK73H1JTTD2202F | 1.00% | 100mW | http://ca.mouser.com/ProductDetail/KOA-Speer/RK73H1JTTD2202F/ | 0.016
R14 | 22k | 0603-RES |  | KOA Speer | RK73H1JTTD2202F | 1.00% | 100mW | http://ca.mouser.com/ProductDetail/KOA-Speer/RK73H1JTTD2202F/ | 0.016
R15 | 43K | 0603-RES |  | KOA Speer | RK73H1JTTD4302F | 1.00% | 100mW | http://ca.mouser.com/ProductDetail/KOA-Speer/RK73H1JTTD4302F/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 | 0.016
R16 | 43K | 0603-RES |  | KOA Speer | RK73H1JTTD4302F | 1.00% | 100mW | http://ca.mouser.com/ProductDetail/KOA-Speer/RK73H1JTTD4302F/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 | 0.016
R17 | 1M | 0603-RES |  | KOA Speer | RK73B1JTTD105J | 5.00% | 100mW | http://ca.mouser.com/ProductDetail/KOA-Speer/RK73B1JTTD105J/?qs=sGAEpiMZZMvdGkrng054t1eDf6HruEFgk7tZ8JYmT6o%3d | 0.018
R18 | 120 | 0603-RES |  | KOA Speer | RK73B1JTTD121J | 5.00% | 100mW | http://ca.mouser.com/ProductDetail/KOA-Speer/RK73B1JTTD121J/ | 0.018
R19 | 330 | 0603-RES |  | KOA Speer | RK73B1JTTDD331J | 5.00% | 100mW | http://ca.mouser.com/ProductDetail/KOA-Speer/RK73B1JTTDD331J/ | 0.018
SJ1 | SOLDERJUMPERTRACE | SJ_2S-TRACE |  |  |  |  |  |  |  | No part to populate – solder jumper WITH TRACE connected by default

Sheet: PartsList
Part | Qty | Value | Package | Manu | Part # | Volt/Precision | Other | Distributor | Link | Supplier # | Cost/1k | Notes
C1-4,6,7,31 | 7 | 0.1u | 0603-CAP | Kemet | C0603C104K4RACTU | X7R | 16V | Mouser | http://ca.mouser.com/ProductDetail/Kemet/C0603C104K4RACTU/ | 80-C0603C104K4R | 0.005
C12 | 1 | 10n | 0603-CAP | TDK | CGJ3E2X7R1H103K | X7R | 50V | Mouser | http://ca.mouser.com/ProductDetail/TDK/CGJ3E2X7R1H103K/ | 810-CGJ3E2X7R1H103K | 0.012
C14 | 1 | 4.7u | 0603-CAP | TDK | C1608X6S1C475K | X6S | 16V | Mouser | http://ca.mouser.com/ProductDetail/TDK/C1608X6S1C475K/ | 810-C1608X6S1C475K | 0.117
C16 | 1 | 10u | 0603-CAP | Nichicon | F981A106MMA | 20.00% | 10V | Mouser | http://ca.mouser.com/ProductDetail/Nichicon/F981A106MMA/ | 647-F981A106MMA | 0.371 | Tantalum capacitor for analog power quality
C17 | 1 | 2.2u | 0603-CAP | TDK | C1608Y5V1C225Z | Y5V | 16V | Mouser | http://ca.mouser.com/ProductDetail/TDK/C1608Y5V1C225Z/ | 810-C1608Y5V1C225Z | 0.021
C21,22,26,27 | 4 | 33p | 0603-CAP | Kemet | C0603C330J5GAC7411 | C0G | 50V | Mouser | http://ca.mouser.com/ProductDetail/Kemet/C0603C330J5GAC7411/?qs=sGAEpiMZZMvQvaS66kI3TnRV7jmGngRVERJ7QEpwH6c%3d | 80-C0603C330J5G7411 | 0.012
C23,28 | 2 | 220u | 1210 | Kemet | TLJB227M006R0500 | 20.00% | 6.3V | Mouser | http://ca.mouser.com/ProductDetail/AVX/TLJB227M006R0500/ | 581-TLJB227M006R0500 | 1.46 | High cost due to size, larger alternative: T491C227M010ZT
C29 | 1 | 47u | PANASONIC_D | Panasonic | EEE-FP1C470AP | 16V | ESR 0.26 | Mouser | http://ca.mouser.com/ProductDetail/Panasonic-Electronic-Components/EEE-FP1C470AP/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 | 667-EEE-FP1C470AP | 0.143
C30 | 1 | 22n | 0603-CAP | Kemet | C0603C223K5RACTU | X7R | 50V | Mouser | http://ca.mouser.com/ProductDetail/Kemet/C0603C223K5RACTU/ | 80-C0603C223K5R | 0.012
C5 | 1 | 10u | 0805 | Kemet | C0805C106K4PACTU | X5R | 16V | Mouser | http://ca.mouser.com/ProductDetail/Kemet/C0805C106K4PACTU/ | 80-C0805C106K4P | 0.071
C8,11,13,15,18,19,20,24,25 | 9 | 1u | 0603-CAP | TDK | C1608X7R1C105K | X7R | 16V | Mouser | http://ca.mouser.com/ProductDetail/TDK/C1608X7R1C105K/?qs=sGAEpiMZZMvQvaS66kI3Tk6Pvfi1sRGOjhNuqGh8w0I%3d | 810-C1608X7R1C105K | 0.019
C9,10 | 2 | 15p | 0603-CAP | Kemet | C0603C150J5GACTU | C0G | 50V | Mouser | http://ca.mouser.com/ProductDetail/Kemet/C0603C150J5GACTU/ | 80-C0603C150J5G | 0.01
D1,2 | 2 | BAT54S | SOT23 | Fairchild | BAT54S | 30V | 0.6A | Mouser | http://ca.mouser.com/ProductDetail/Fairchild-Semiconductor/BAT54S/ | 512-BAT54S | 0.032
IC1 | 1 | FT232RLSSOP | SSOP28DB | FTDI | FT232RL-REEL | 5.25V |  | Mouser | http://ca.mouser.com/ProductDetail/FTDI/FT232RL-REEL/ | 895-FT232RL | 2.84
IC2 | 1 | LP2981 | SOT23-5 | TI | TPS73028DBVT | 2.8v | 200mA | Mouser | http://ca.mouser.com/ProductDetail/Texas-Instruments/TPS73028DBVT/ | 595-TPS73028DBVT | 0.416
IC3 | 1 | LM4808MM | SO8 | TI | LM4808M/NOPB | 5.5v | 150mW | Digikey | http://www.digikey.com/product-detail/en/LM4808M%2FNOPB/LM4808M%2FNOPB-ND/364157 | LM4808M/NOPB-ND | 0.336
IC4 | 1 | WT32 | WT32 | Bluegiga | WT32-A-AI4 | 3.3v |  | Mouser | http://ca.mouser.com/ProductDetail/Bluegiga-Technologies/WT32-A-AI4/ | 603-WT32-A-AI4 | 25.68 | WT32-A-AI5 should be a valid upgrade once stock is available
IC5 | 1 | TLE4284DV33 | V-REG_DPACK | Infineon | TLE4284D V33 | 3.3V | 1A | Digikey | http://www.digikey.ca/product-detail/en/TLE4284D%20V33/TLE4284D%20V33TR-ND/1016100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 | TLE4284D V33TR-ND | 1.025
J1 | 1 | USB-A-H | USB-A-H | Samtec | USB-AM-S-F-B-TH | 1A |  | Arrow | http://components.arrow.com/part/detail/43114295S7160411N1004?region=na | USB-AM-S-F-B-TH | 0.8266 | Any USB-AM-S will do, sparkfun part # PRT-00437 also valid
J2 | 1 | AUDIO-JACK-4PSWSJ-43515 | SJ-4351X | CUI Inc | SJ-43514 |  | 4 Conductor | Digikey | http://www.digikey.com/product-detail/en/SJ-43514/CP-43514-ND/368146 | CP-43514-ND | 0.552
L1,2 | 2 | 15n | 603 | Taiyo Yuden | HK160815NJ-T | 0.3nH | 0.3A | Mouser | http://ca.mouser.com/ProductDetail/Taiyo-Yuden/HK160815NJ-T/ | 963-HK160815NJ-T | 0.039
L3 | 1 | BK0603HS330 | 603 | Taiyo Yuden | BKP1608HS330-T | 25.00% | 3A | Mouser | http://ca.mouser.com/ProductDetail/Taiyo-Yuden/BKP1608HS330-T/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 | 963-BKP1608HS330-T | 0.042
L4 | 1 | 10u | 603 | TDK | MLZ1608N100L | 20.00% | 300mA | Mouser | http://ca.mouser.com/ProductDetail/TDK/MLZ1608N100L/ | 810-MLZ1608N100L | 0.059
LED1,4 | 2 | TX | LED-0603 | Kingbright | APA1606SURCK | 1.95v | 20mA | Mouser | http://ca.mouser.com/ProductDetail/Kingbright/APA1606SURCK/?qs=sGAEpiMZZMtEjy7lsqBi5QZiKsKozmc0xPh23Fre9Nk%3d | 604-APA1606SURCK | 0.077 | Red
LED2,3 | 2 | RX | LED-0603 | Kingbright | APA1606SGC | 2.2v | 20mA | Mouser | http://ca.mouser.com/ProductDetail/Kingbright/APA1606SGC/ | 604-APA1606SGC | 0.096 | Green
R1-3 | 3 | 1k | 0603-RES | KOA Speer | RK73B1JTTD102J | 5.00% | 100mW | Mouser | http://ca.mouser.com/ProductDetail/KOA-Speer/RK73B1JTTD102J/ | 660-RK73B1JTTD102J | 0.018
R4,R18 | 2 | 120 | 0603-RES | KOA Speer | RK73B1JTTD121J | 5.00% | 100mW | Mouser | http://ca.mouser.com/ProductDetail/KOA-Speer/RK73B1JTTD121J/ | 660-RK73B1JTTD121J | 0.018
R5,19 | 2 | 330 | 0603-RES | KOA Speer | RK73B1JTTDD331J | 5.00% | 100mW | Mouser | http://ca.mouser.com/ProductDetail/KOA-Speer/RK73B1JTTDD331J/ | 660-RK73B1JTTDD331J | 0.018
R10,11,15,16 | 4 | 43K | 0603-RES | KOA Speer | RK73H1JTTD4302F | 1.00% | 100mW | Mouser | http://ca.mouser.com/ProductDetail/KOA-Speer/RK73H1JTTD4302F/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 | 660-RK73H1JTTD4302F | 0.016
R12,17 | 2 | 1M | 0603-RES | KOA Speer | RK73B1JTTD105J | 5.00% | 100mW | Mouser | http://ca.mouser.com/ProductDetail/KOA-Speer/RK73B1JTTD105J/?qs=sGAEpiMZZMvdGkrng054t1eDf6HruEFgk7tZ8JYmT6o%3d | 660-RK73B1JTTD105J | 0.018
R6,7 | 2 | 100k | 0603-RES | KOA Speer | RK73B1JTTD104J | 5.00% | 100mW | Mouser | http://ca.mouser.com/ProductDetail/KOA-Speer/RK73B1JTTD104J/?qs=sGAEpiMZZMvdGkrng054t1eDf6HruEFgwpPTqQd3kEE%3d | 660-RK73B1JTTD104J | 0.018
R8,9,13,14 | 4 | 22k | 0603-RES | KOA Speer | RK73H1JTTD2202F | 1.00% | 100mW | Mouser | http://ca.mouser.com/ProductDetail/KOA-Speer/RK73H1JTTD2202F/ | 660-RK73H1JTTD2202F | 0.016

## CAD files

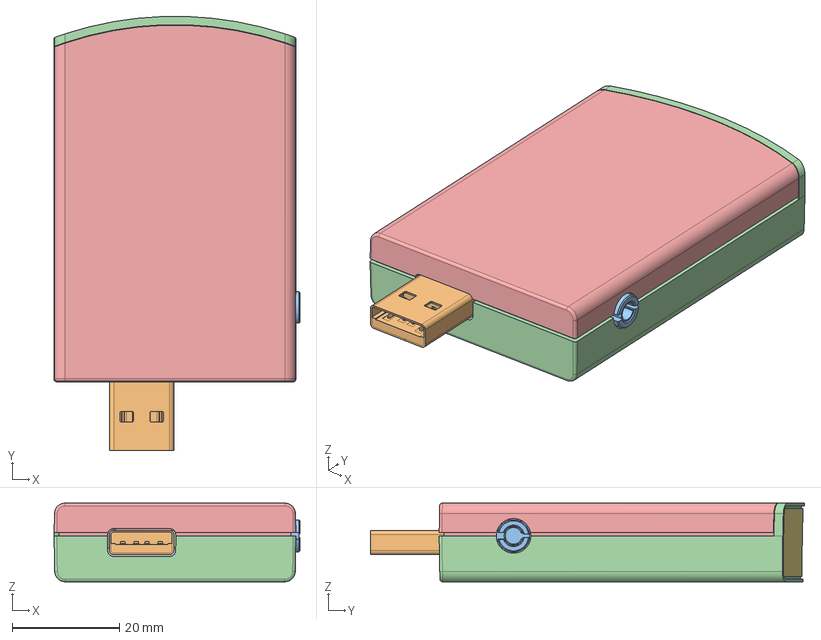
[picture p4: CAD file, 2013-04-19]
enclosure/ijoey_assy_reva_asm.stp
45.9 x 81.0 x 14.7 mm
IJOEY_PCB_REVZ01
USB-AM-S-X-X-TH
SJ-43514
IJOEY_TOP_REVA
IJOEY_BOTTOM_REVA
M2_SCREW_91698A206 x 4
IJOEY_LABEL_REVA

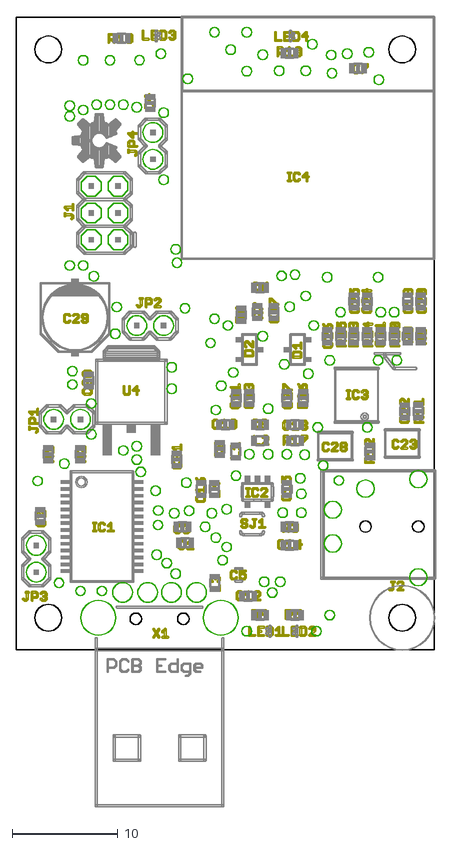
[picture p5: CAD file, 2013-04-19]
schematics/fabrication/BT_Audio_iJoey.dxf
39.8 x 74.9

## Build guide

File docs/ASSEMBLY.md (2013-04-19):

Vehicle Interface Assembly Instructions
=======================================

Special Assembly Instructions
-----------------------------

*	Verify LED3 and LED4 have been installed  as right-angle LEDs - the LED
	package is ambiguous and can be mounted either way.

Assembly file output instructions
---------------------------------

*	Verify silkscreen and PCB Frame artwork reflects accurate revision
*	Update layer 125 text on top of each component should identify the part
	designator
*	Delete all content on layer (144) DrillLegend
*	run "drillegend.ulp": Use all default values, click OK.
*	Reselect layer (144) and move the newly created drill legend back onto the
	frame
*	Verify SSC-EAGLE-2Lyr_v1.0.0.3.dru is loaded as current design rules file
*	Turn on all copper and stopmask layers, turn off silkscreen layers (skip
	silkscreen error checking, silkscreen will be clipped by assembly house)
*	Preform DRC/ERC check
*	run "drillcfg.ulp": select "Inch" as output format.  Click OK.  Save.
*	run "excellon.cam" in the CAM processor, click "Process Job"
*	run "2LPlus-Sunstone.cam" in the CAM processor, click "Process Job"
*	Double check all gerber files using a gerber file viewer (like gerbv).
*	Deselect all layers, select only the following layers:
	(17)Pads, (18)Vias, (20)Dimension, (21)tPlace, (22)bPlace, (23)tOrigins,
	(24)bOrigins, (49)Reference, (51)tDocu, (52)bDocu, (125)tAssy
*	run "dxf.ulp": deselect "Fill Areas", make sure "mm" is selected under the
	"units" header.  Save the DXF file.
*	Deselect all layers, select only the following layers:
	(17)Pads, (18)Vias, (20)Dimension, (21)tPlace, (23)tOrigins, (48)Document,
	(49)Reference, (51)tDocu, (125)tAssy, (144)DrillLegend
*	Hit print (Ctrl+P), select "Print to File (PDF)" as the printer, select
	BT_Audio_iJoey_ASSY.pdf, paper size A4, scale factor 1.  Click OK.
*	Deselect all layers, select only the following layers:
	(1)Top, (16)Bottom, (17)Pads, (18)Vias, (20)Dimension, (21)tPlace,
	(22)bPlace, (25)tNames, (51)tDocu, (52)bDocu
*	Zoom in so that PCB is centered in the screen and fills the window as much
	as possible.
*	Select File->Export->Image.  Select BT_Audio_iJoey.brd.png.  Set
	"Resolution" to 600.  Set "Area" to "Window".
*	In the schematic window, hit print (Ctrl+P), select "Print to File (PDF)" as
	the printer, select BT_Audio_iJoey.sch.pdf, paper size A4, scale factor 1,
	page limit 1  Click OK.
*	In the schematic window, select File->Export->Partlist.  Select
	"BT_Audio_iJoey.parts.txt".  Click OK.
*	Manually compare "BT_Audio_iJoey.parts.txt" to "BT_Audio_iJoey.bom.xls".
	Make sure the two lists are consistent.
*	Open "CAN Translator Changelog + Testing.xls".  Update the file to reflect
	the new revision.
*	Create a zip archive with the following files (at least):
	*	BT_Audio_iJoey.sch.pdf
	*	BT_Audio_iJoey.brd.png
	*	BT_Audio_iJoey_ASSY.pdf
	*	BT_Audio_iJoey.tsp
	*	BT_Audio_iJoey.top
	*	BT_Audio_iJoey.smt
	*	BT_Audio_iJoey.smb
	*	BT_Audio_iJoey.slk
	*	BT_Audio_iJoey.oln
	*	BT_Audio_iJoey.gpi
	*	BT_Audio_iJoey.dxf
	*	BT_Audio_iJoey.drl
	*	BT_Audio_iJoey.dri
	*	BT_Audio_iJoey.drd
	*	BT_Audio_iJoey.bsp
	*	BT_Audio_iJoey.bsk
	*	BT_Audio_iJoey.bot
	*	BT_Audio_iJoey.bom.xls
	*	BT_Audio_iJoey.sch
	*	BT_Audio_iJoey.brd
	*	BT_Audio_Testing-Changelog.xls

Factory Testing Plan
--------------------

This testing plan will require a simple voltmeter as well as linux host of some
kind with USB, audio, and Bluetooth interfaces.  The voltmeter can be soldered
to a 2-pin 0.1" pitch male header, to be inserted into JP2 during testing.  Code
could be written using pyserial and pybluez to preform the test routine:

1.	Connect BT Audio Accessory to a USB power source
1.	Connect a meter to JP2, verify +3.3V rail is within range
1.	Check linux host (lsusb, /sys/bus/usb, /var/log/kern.log) to see if device
	has enumerated properly
1.	Preform [the WT32 configuration procedure in the Readme document](./README.html#how-to-program)
1.	Power-cycle the BT Audio Accessory
1.	Verify LED4 is lit RED
1.	Scan and pair with the BT Audio Accessory over Bluetooth
1.	Connect to the A2DP service
1.	Verify LED3 is lit GREEN and LED4 is not lit.
1.	Play audio through the A2DP Sink and record it using the Line IN of the
	linux host
1.	Preform audio analysis on the played verses recorded samples.
1.	Reconfigure the WT32 as an [A2DP Source using the Readme document](./README.html#a2dp-source-audio-from-microphone-to-bluetooth)
1.	Reconnect to the WT32 using bluetooth
1.	Play audio through the Line OUT of the linux host, and record using the A2DP
	Source
1.	Preform audio analysis on the played verses recorded samples.
1.	Reconfigure the WT32 as an [A2DP Sink using the Readme document](./README.html#a2dp-sink-audio-from-bluetooth-to-speaker)

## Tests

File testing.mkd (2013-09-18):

**Electrical**

* Must be powered via a USB port
* Must be able to pair from Android phone, Android tablet, iPhone and a PC with
  a Bluetooth adapter with a default pre-arranged passcode (1234 is fine)
* Must appear as an A2DP device to all Bluetooth connections
* Audio stream quality must be imperceptibly different from SYNC Bluetooth (i.e.
  vs Bluetooth iJoey to SYNC aux-in port) (e.g. no pops or clicks, not overly
  compressed, no EQ compression)
* LED activates when powered
* A separate LED activates when paired and transmitting audio, or the color of a
  single LED changes
* Stream audio for 12 hours and record all disconnections and transmissions
  errors
* Run through 100 connect/disconnect cycles, looking for failures to connect, or
  any instance in which the Bluetooth stack becomes out of sync
* Must be capable of a reasonable amount of gain (added after the fact) (0xE,
  -6dB works well with SYNC)

**Physical**

* iJoey must be able to go through 100 attach/detach procedures with the k-board
  with no visible wear

**Mechanical**

* Cast urethane parts, designed for injection molding --> Constant wall
  thickness, appropriate minimum thickness material (0.050" for ABS), draft
  angles, slide consideration
* Robust attachment and mating features between housing pieces
* Assuming a K-Board installed into a 2012 Focus cup holder, BT iJoey must fit
  appropriately in provided space

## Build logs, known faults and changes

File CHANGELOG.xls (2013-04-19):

What | Where | Criteria | done? | Severity | Notes
R0.1
Green LED intensity | LED2,3 | Split R18, add 330 ohm for red LED, add one for Green LED | YES | 1 | Find resistors to make green roughly equal to red in brightness.
Improve PSRR | Schematic | Reduce noise at output from USB power | NO | 2 | Audio quality good enough for this revision
LEDs are side-mounted | Assembly Notes | All board LEDs must be mounted facing outwards | YES | 3 | Add assembly note so CM knows to mount this correctly.
Center LED3+LED4 on top edge | Layout |  | YES | 1
Move LED1+LED2 away | Layout | Could be back towards FTDI chip or USB connector | YES | 1
R0.2
Severity:
1: Purely Optional or Cosmetic
2: Enhancing reliability or robustness
3: A reworkable error
4: Not easily reworked, noncritical
5: Critical to main board operation

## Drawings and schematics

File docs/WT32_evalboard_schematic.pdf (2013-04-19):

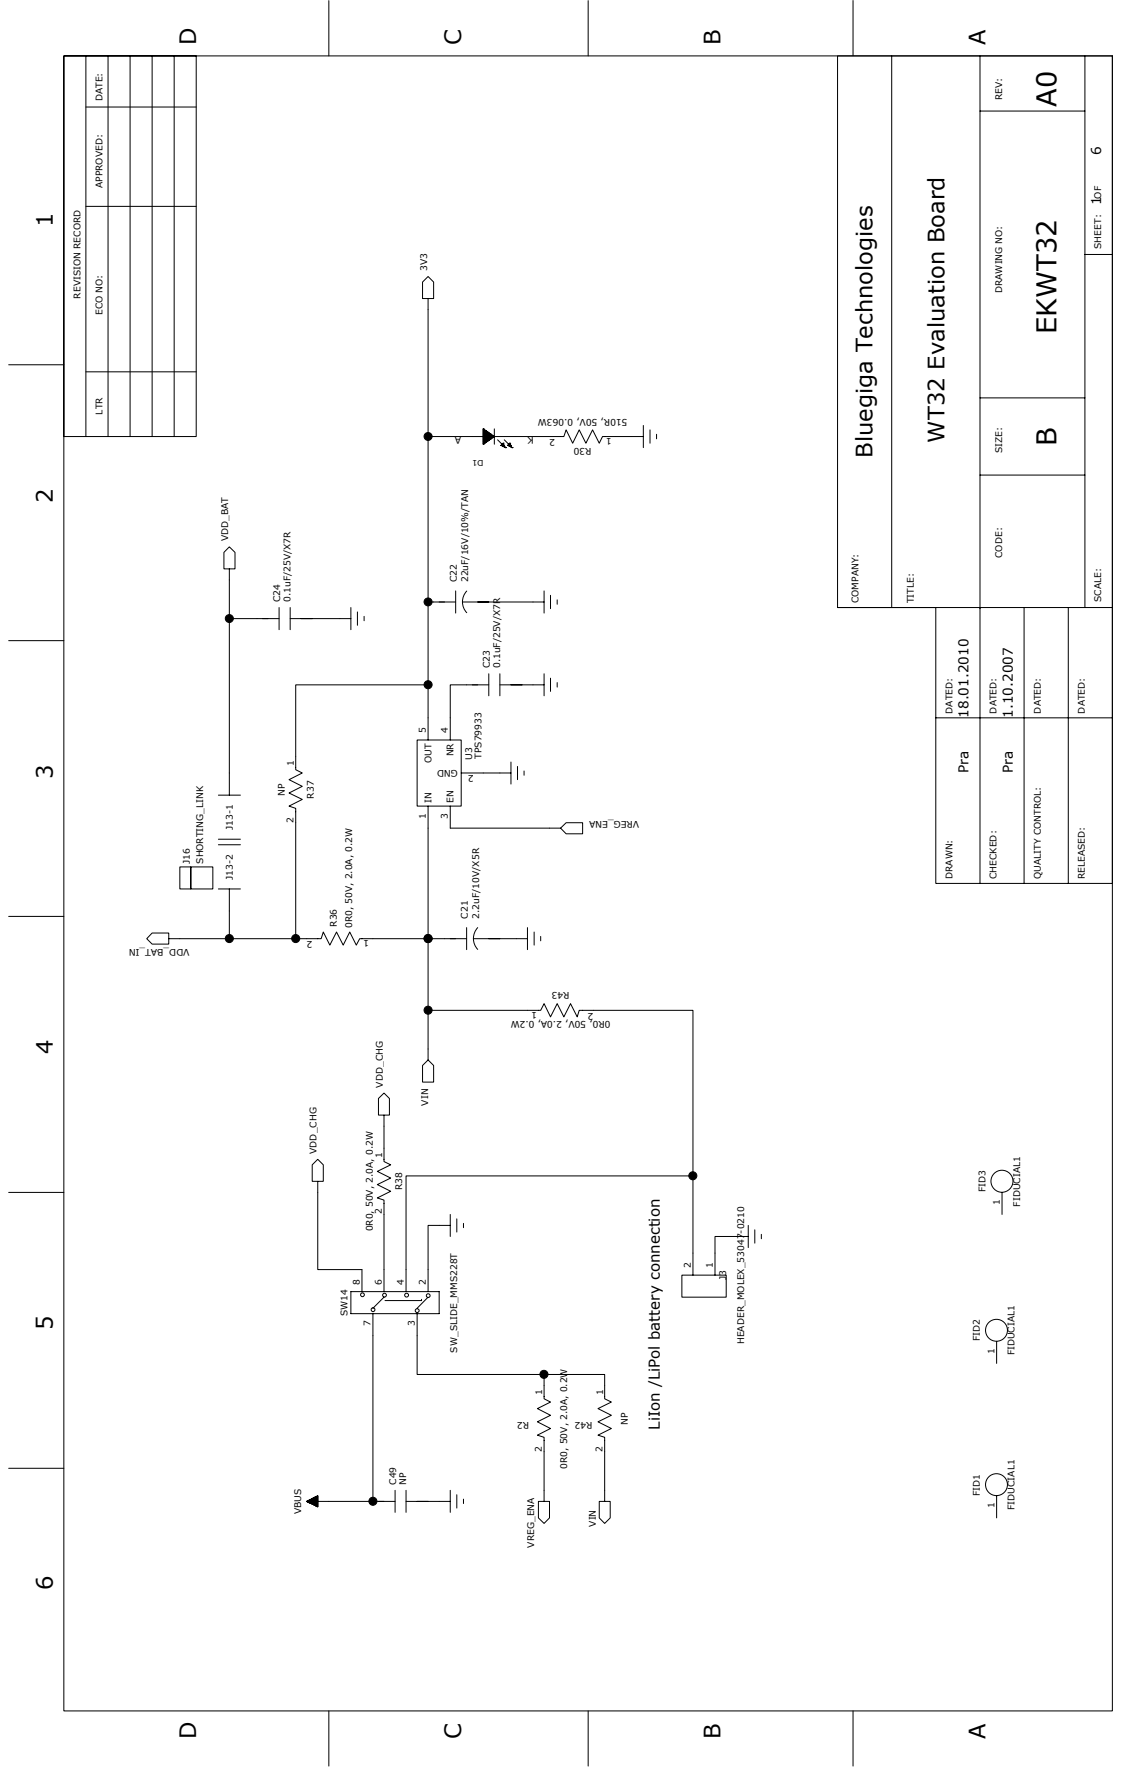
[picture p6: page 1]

LiIon /LiPol battery connection

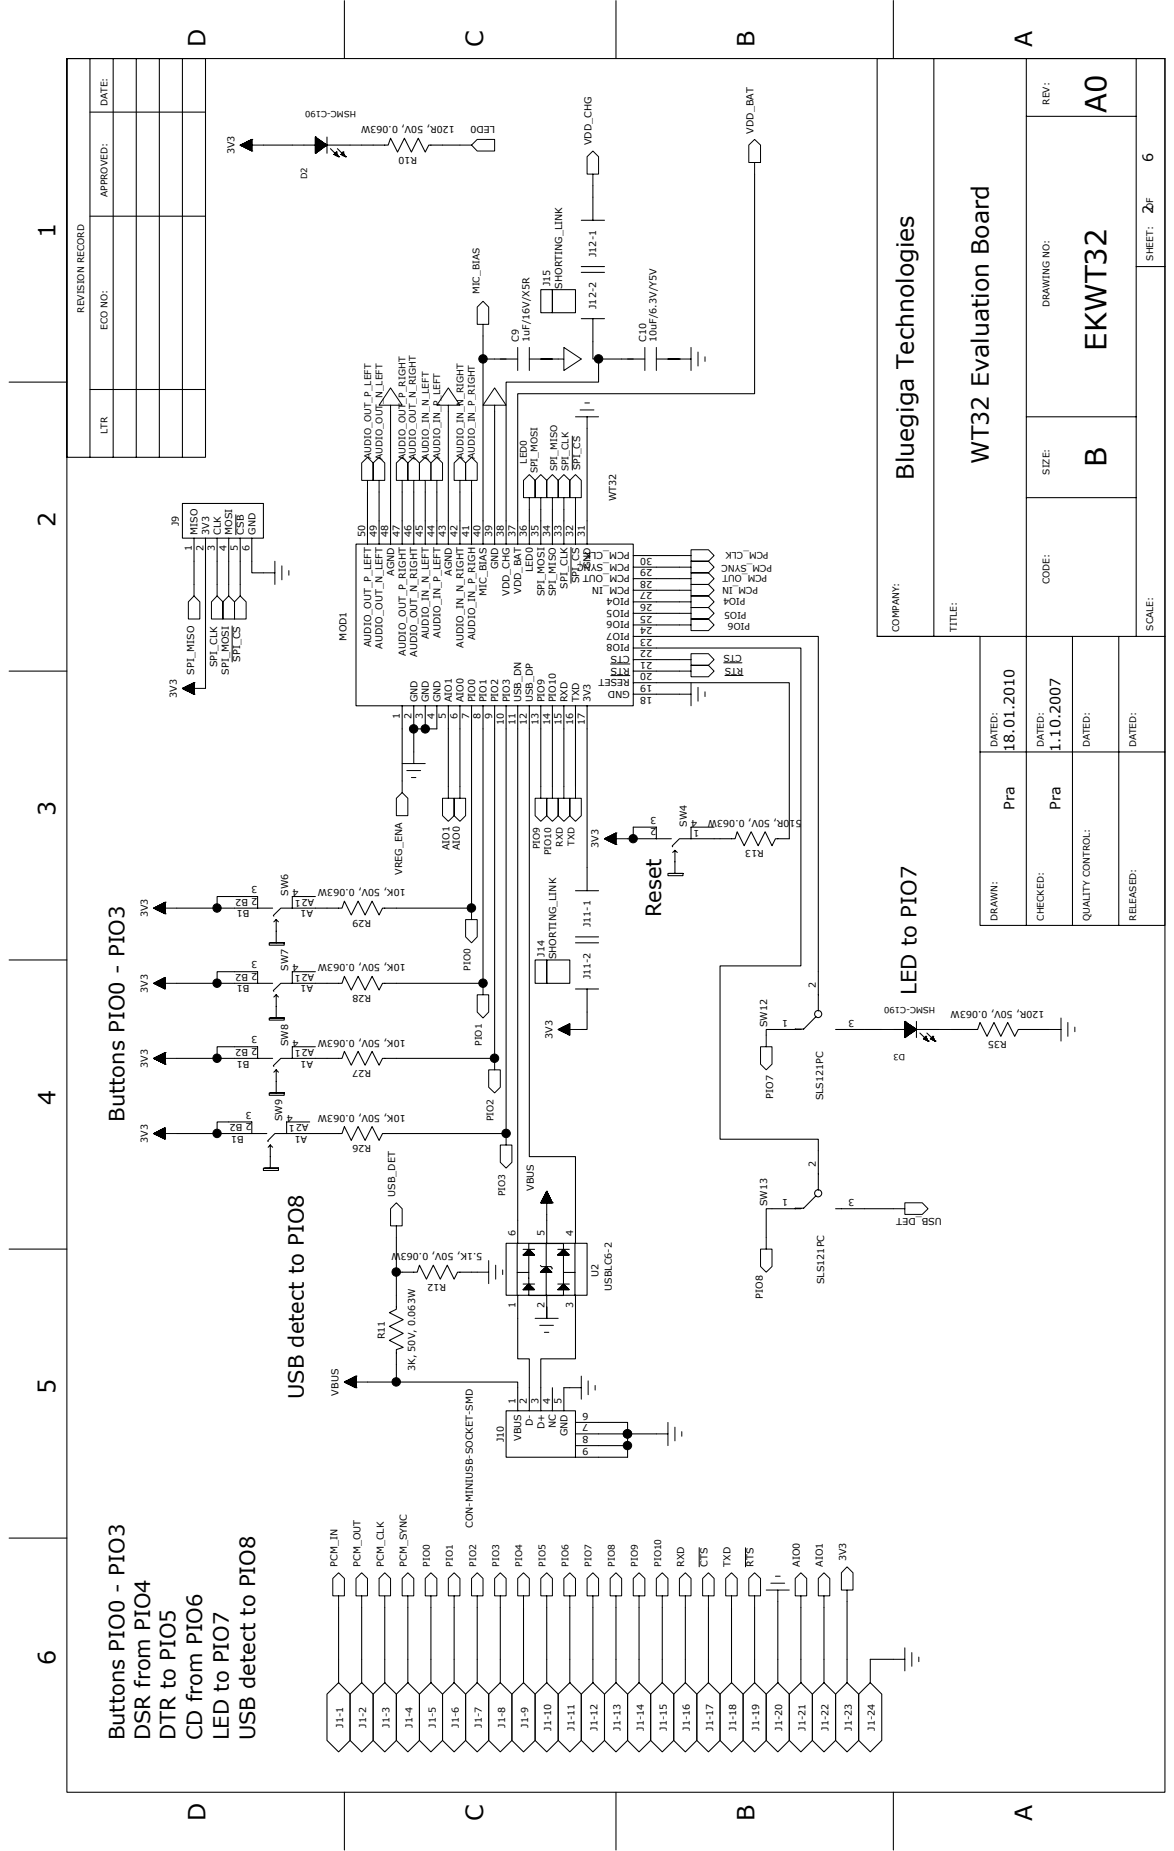
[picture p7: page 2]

2 GND 3 GND 4 GND 5 AIO1 6 AIO0 7 PIO0 8 PIO1 9 PIO2 10 PIO3 11 USB_DN 12 USB_DP 13 PIO9 14 PIO10 15 RXD 16 TXD 17 3V3

CON-MINIUSB-SOCKET-SMD

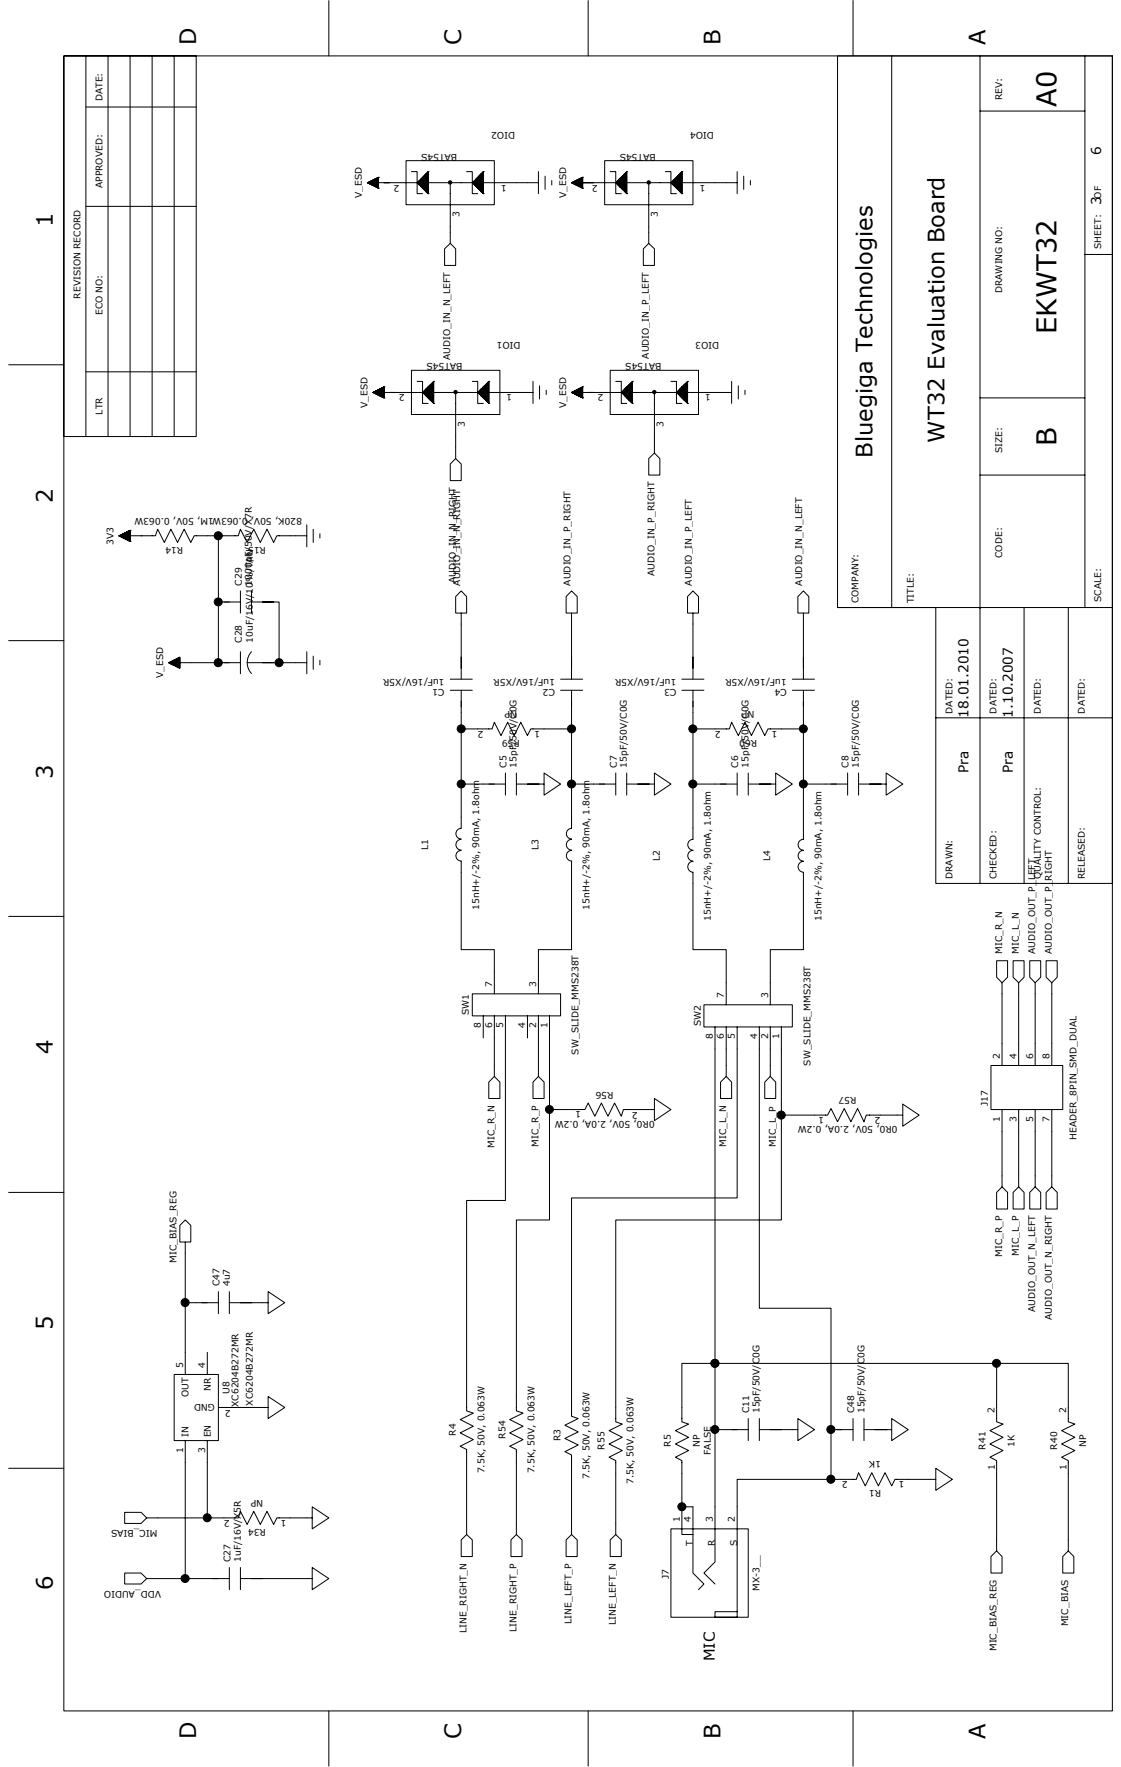
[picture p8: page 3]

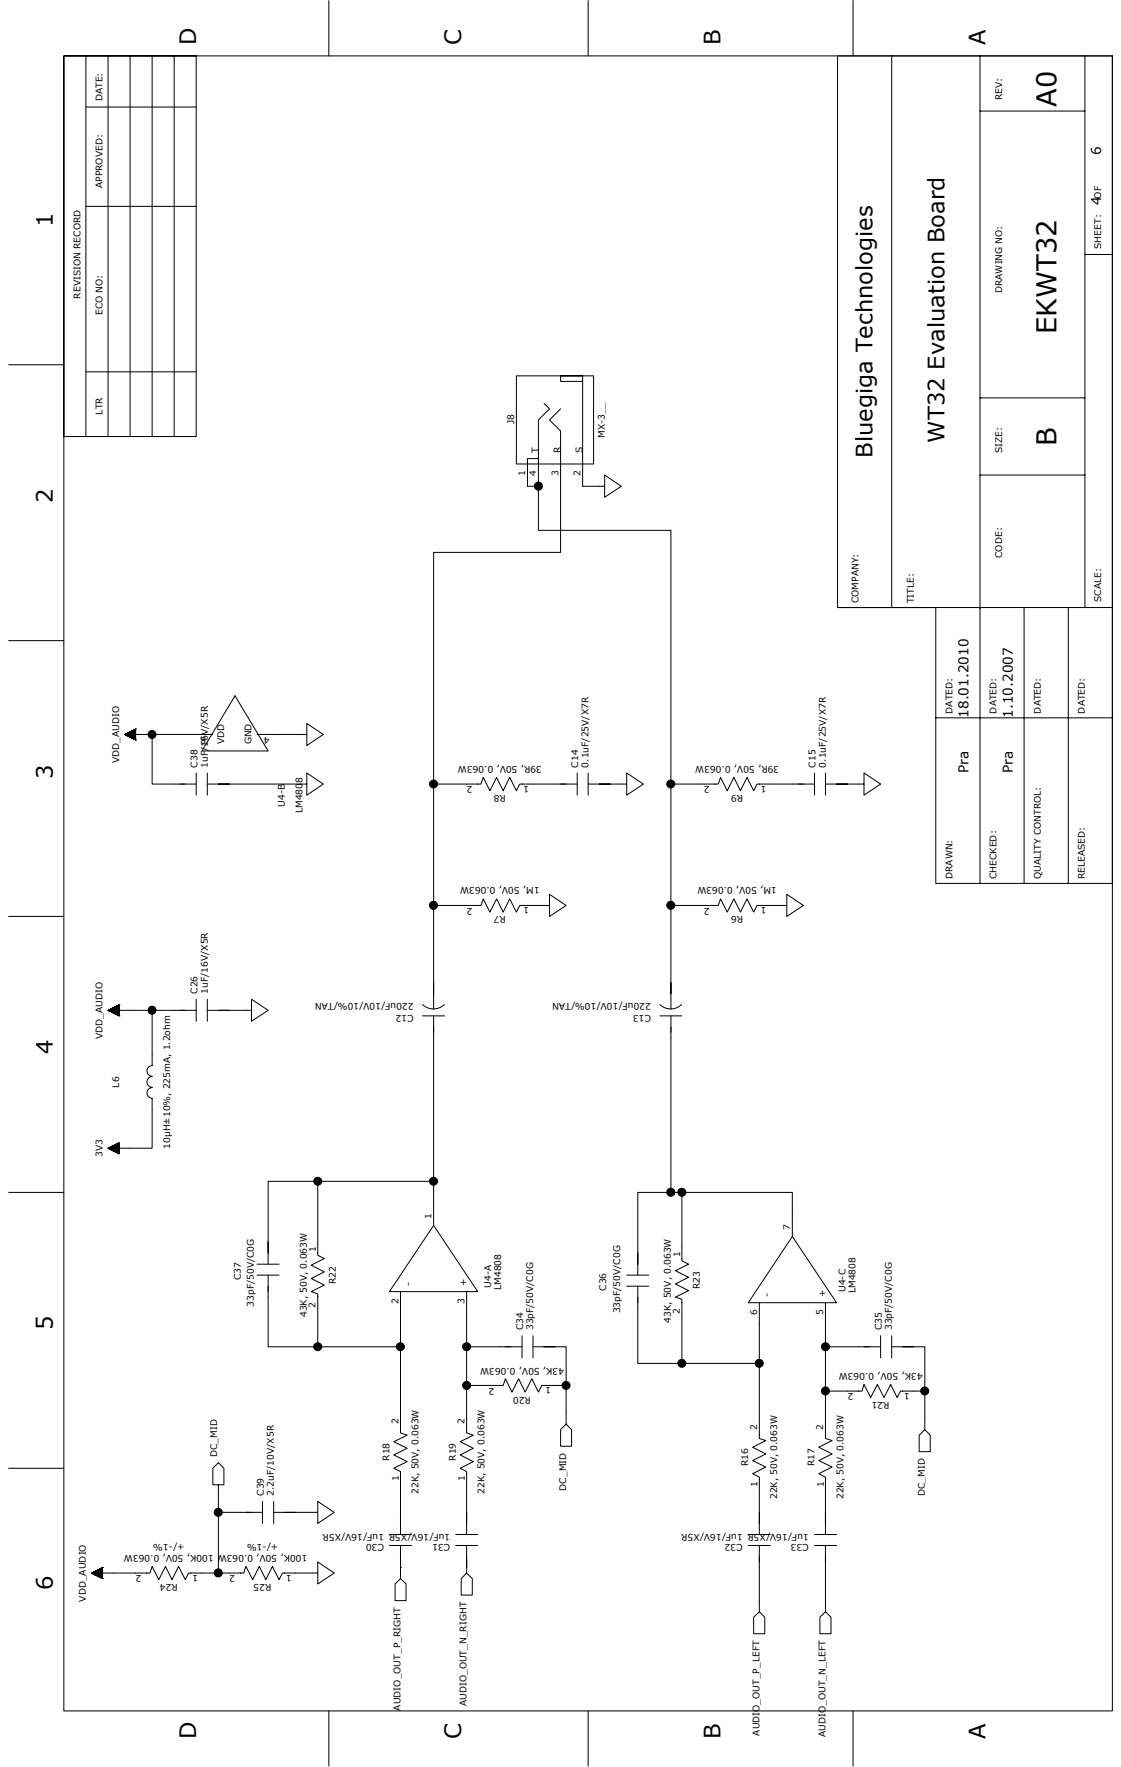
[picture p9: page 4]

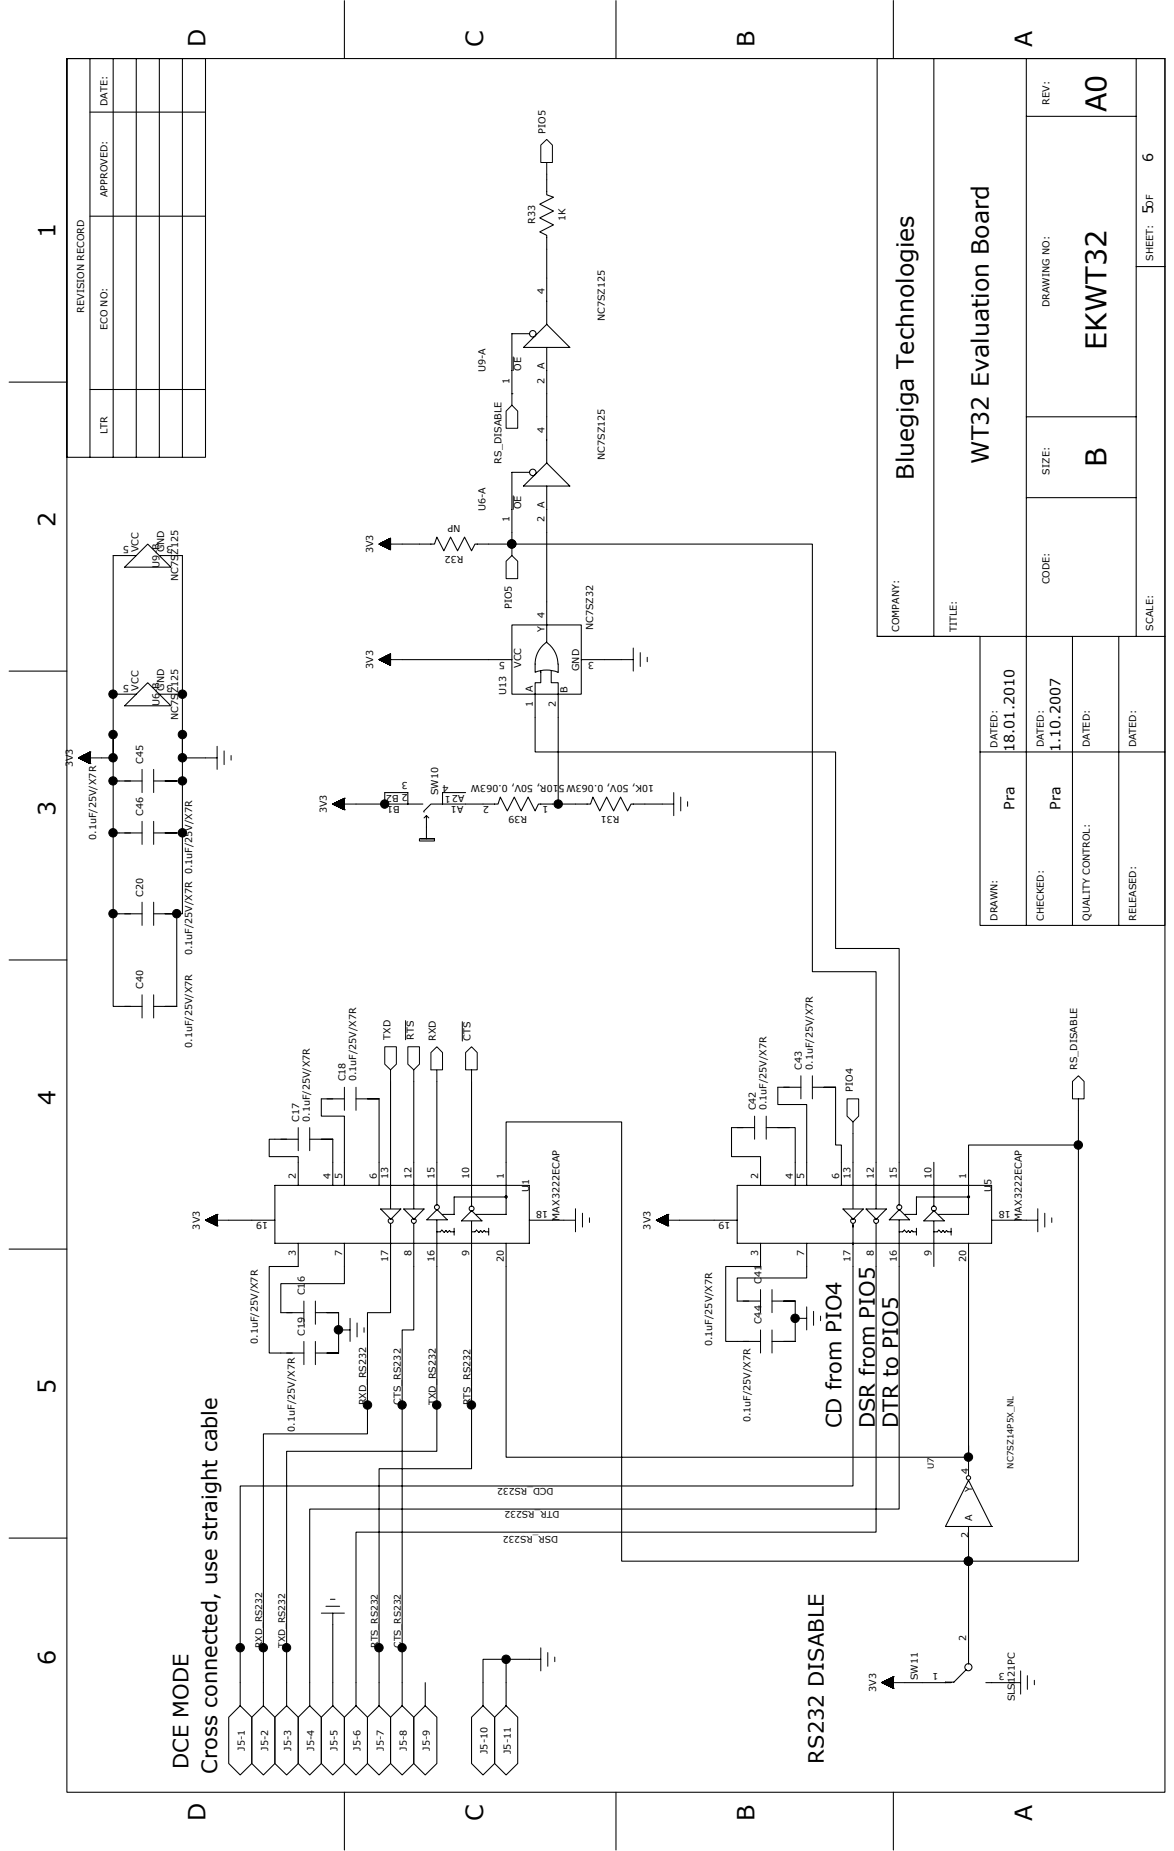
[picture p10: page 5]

Cross connected, use straight cable

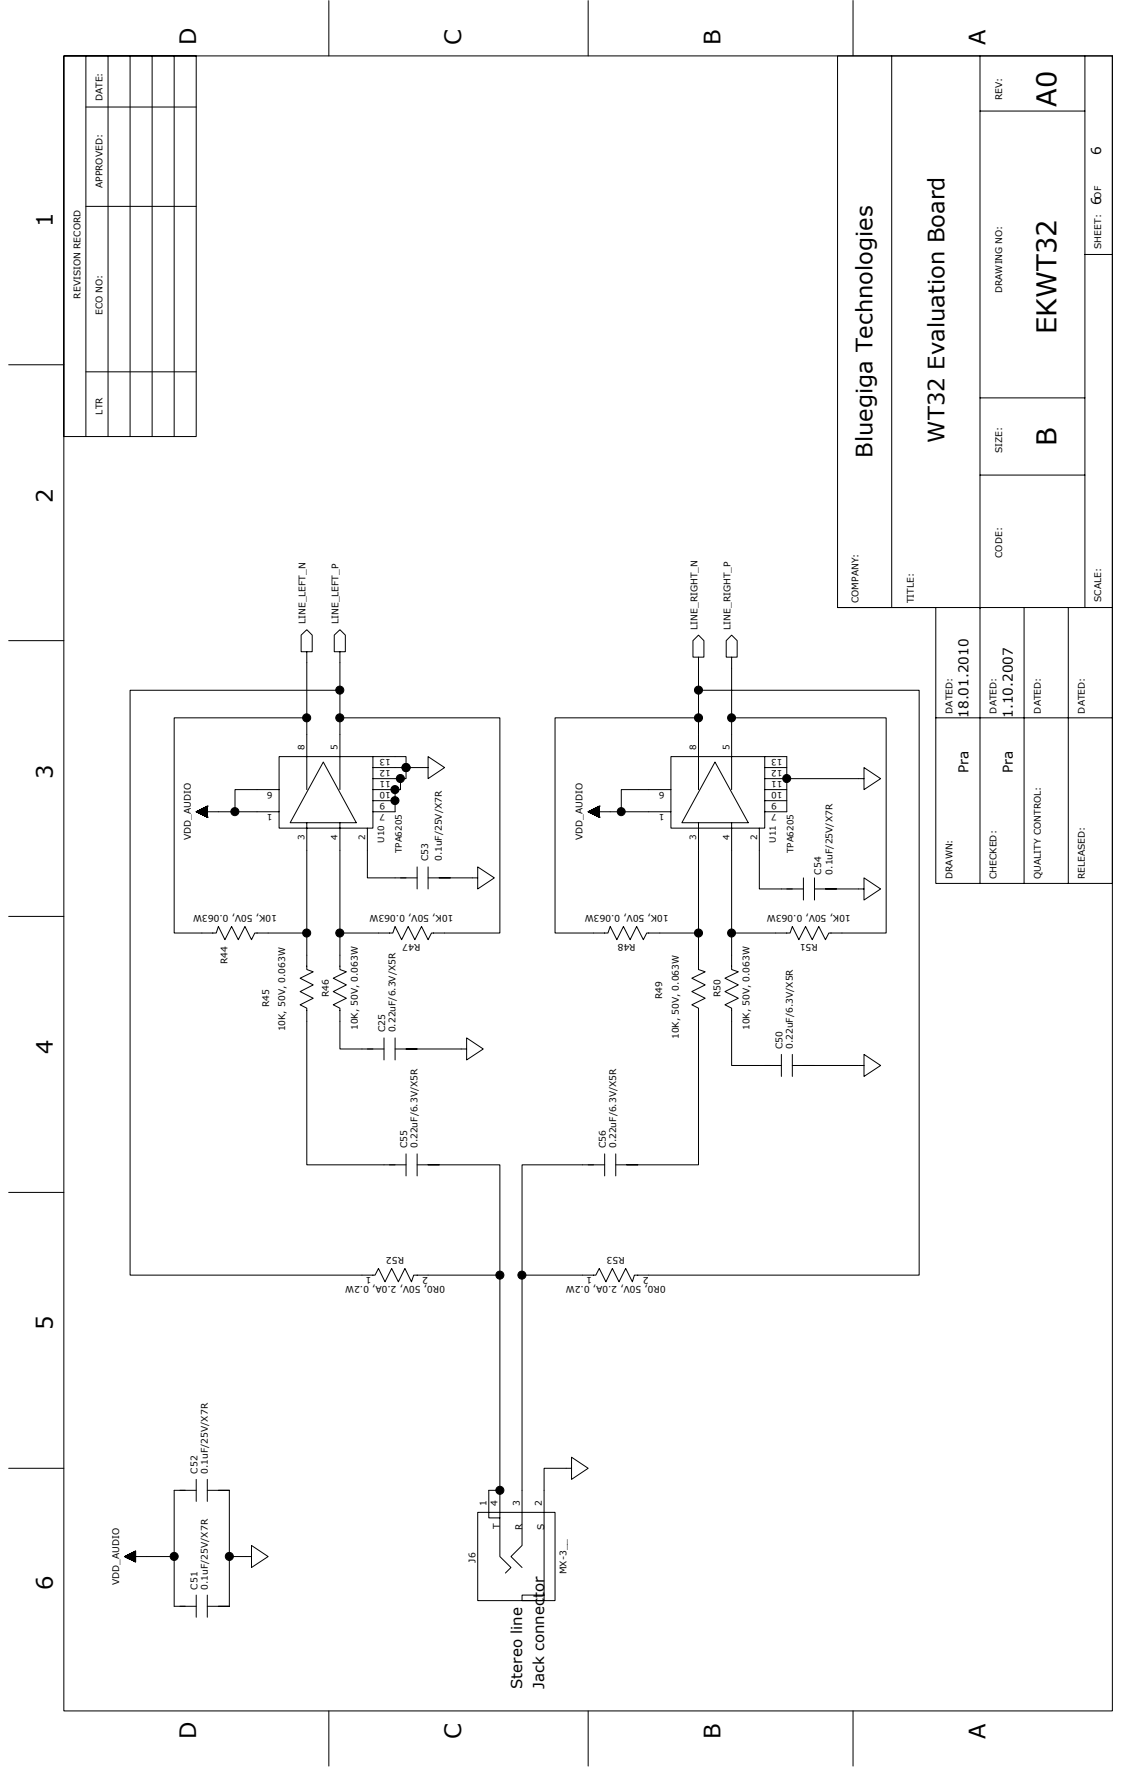
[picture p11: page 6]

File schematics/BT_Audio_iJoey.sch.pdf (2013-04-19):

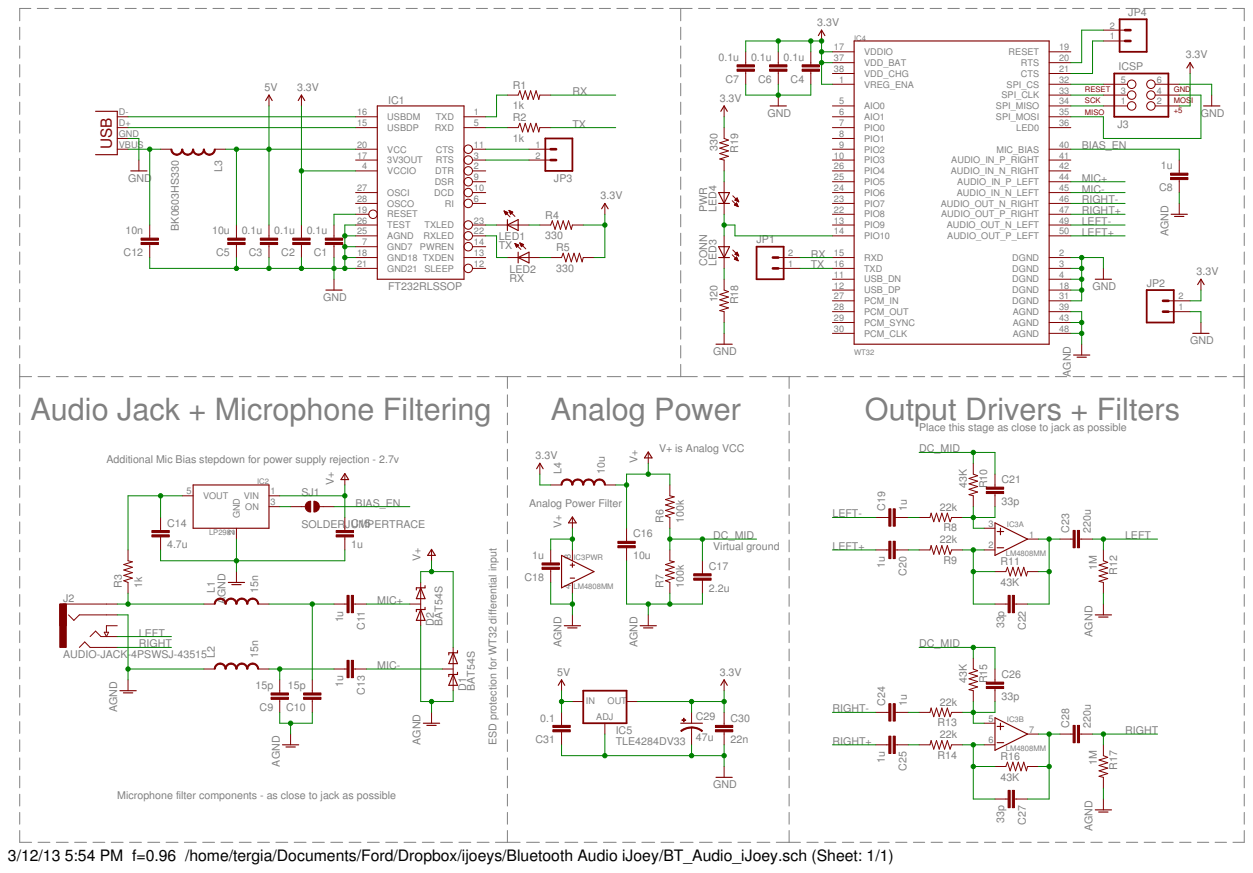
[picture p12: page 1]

ESD protection for WT32 differential input

Microphone filter components - as close to jack as possible

3/12/13 5:54 PM f=0.96 /home/tergia/Documents/Ford/Dropbox/ijoeys/Bluetooth Audio iJoey/BT_Audio_iJoey.sch (Sheet: 1/1)

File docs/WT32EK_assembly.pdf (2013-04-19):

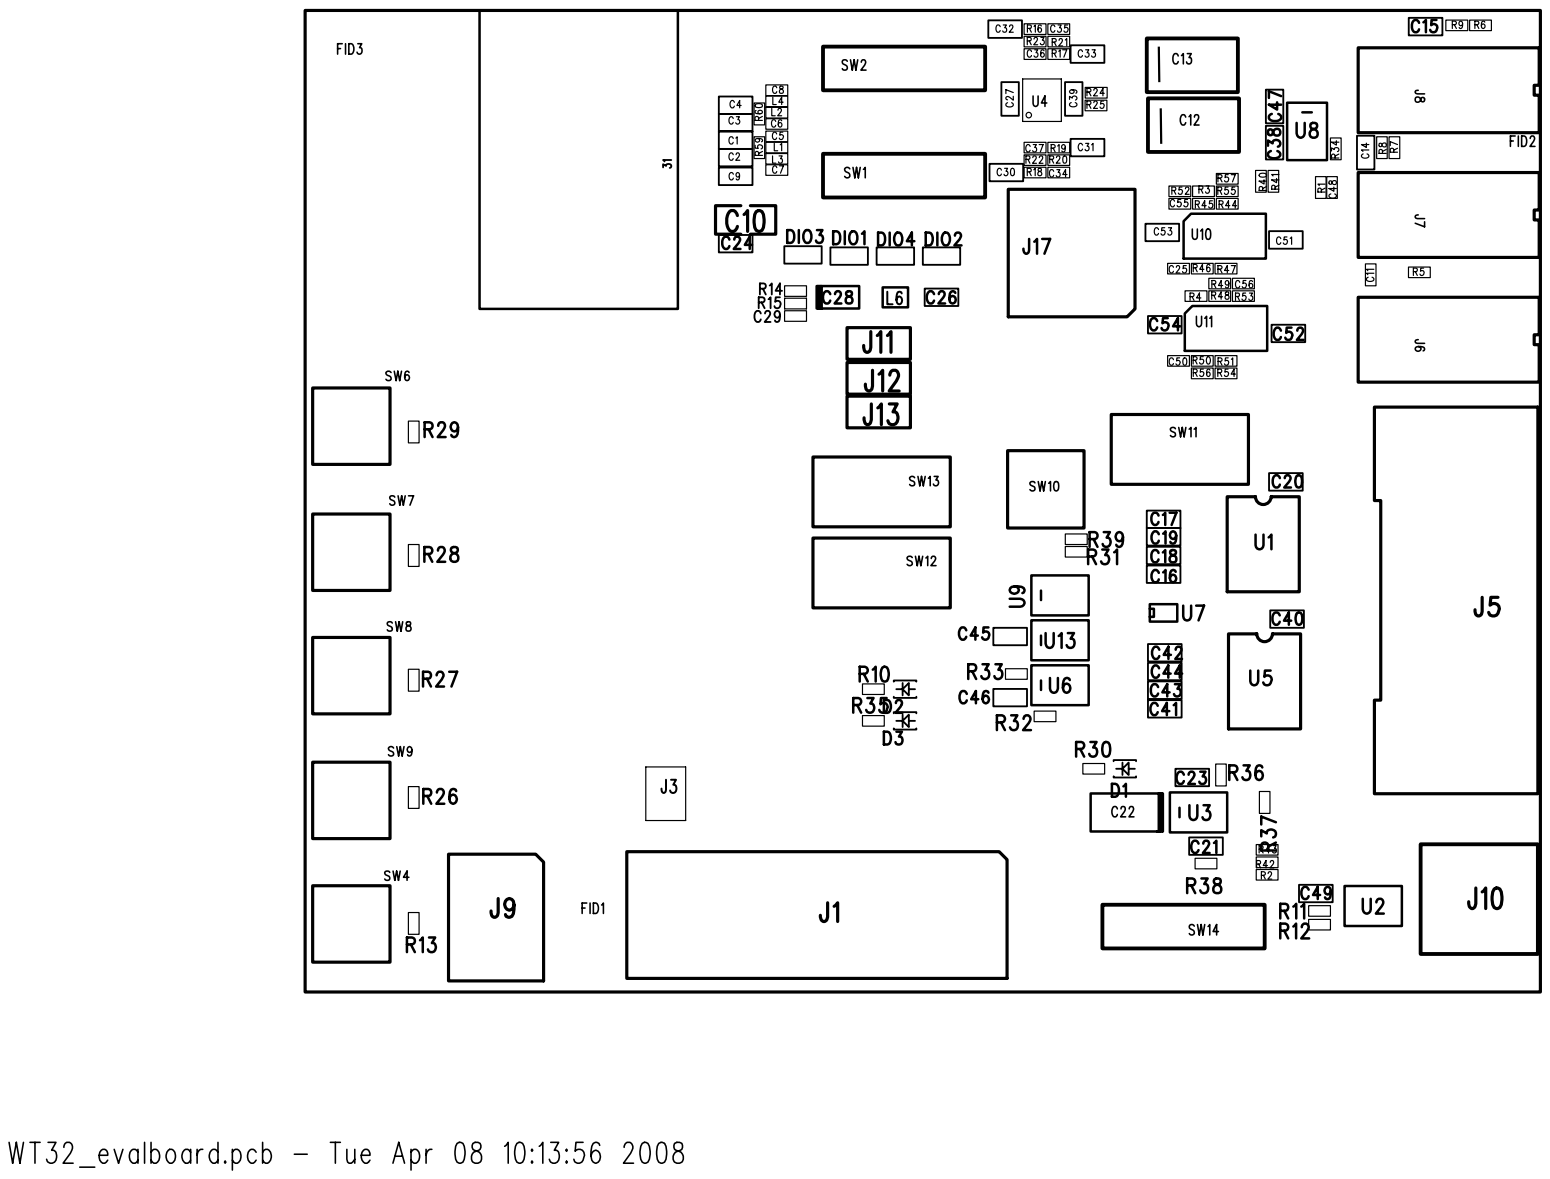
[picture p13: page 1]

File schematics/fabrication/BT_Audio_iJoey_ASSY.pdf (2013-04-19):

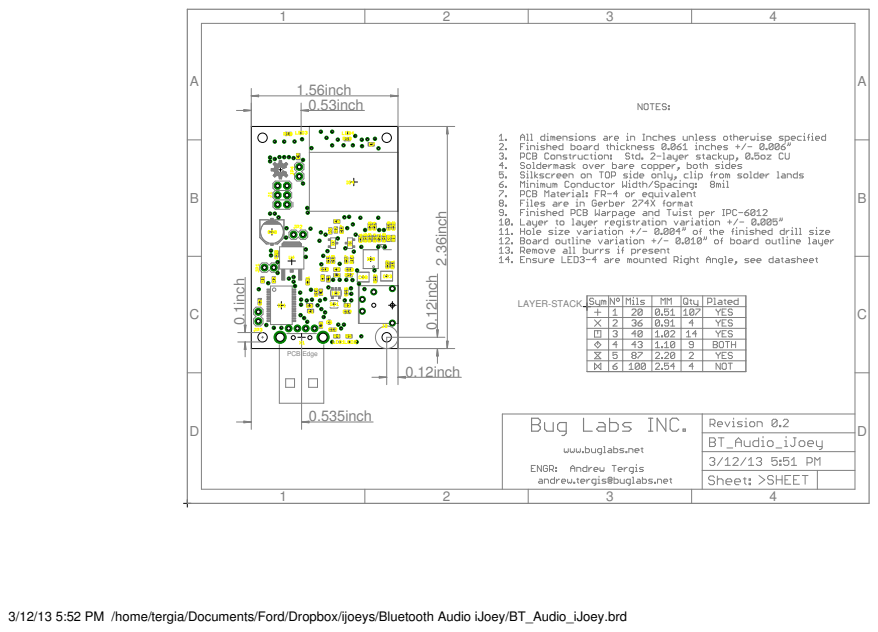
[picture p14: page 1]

3/12/13 5:52 PM /home/tergia/Documents/Ford/Dropbox/ijoeys/Bluetooth Audio iJoey/BT_Audio_iJoey.brd

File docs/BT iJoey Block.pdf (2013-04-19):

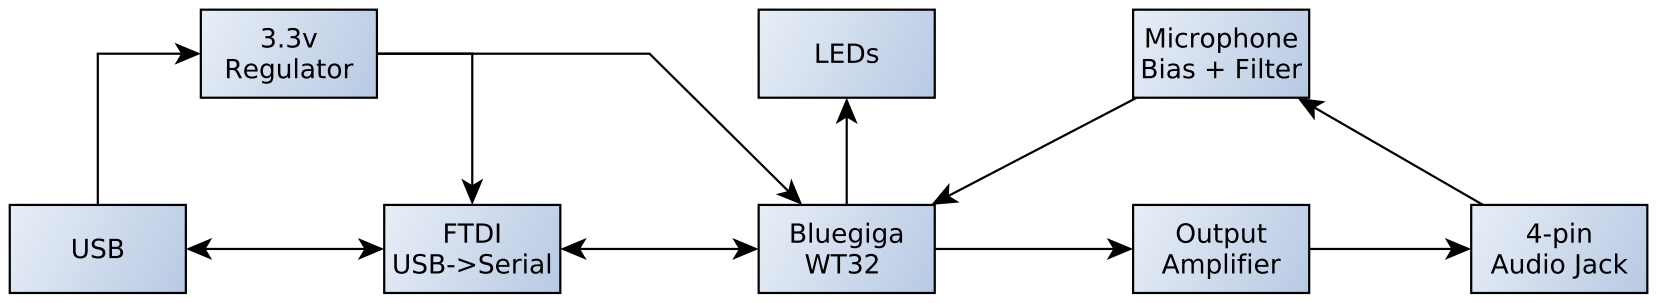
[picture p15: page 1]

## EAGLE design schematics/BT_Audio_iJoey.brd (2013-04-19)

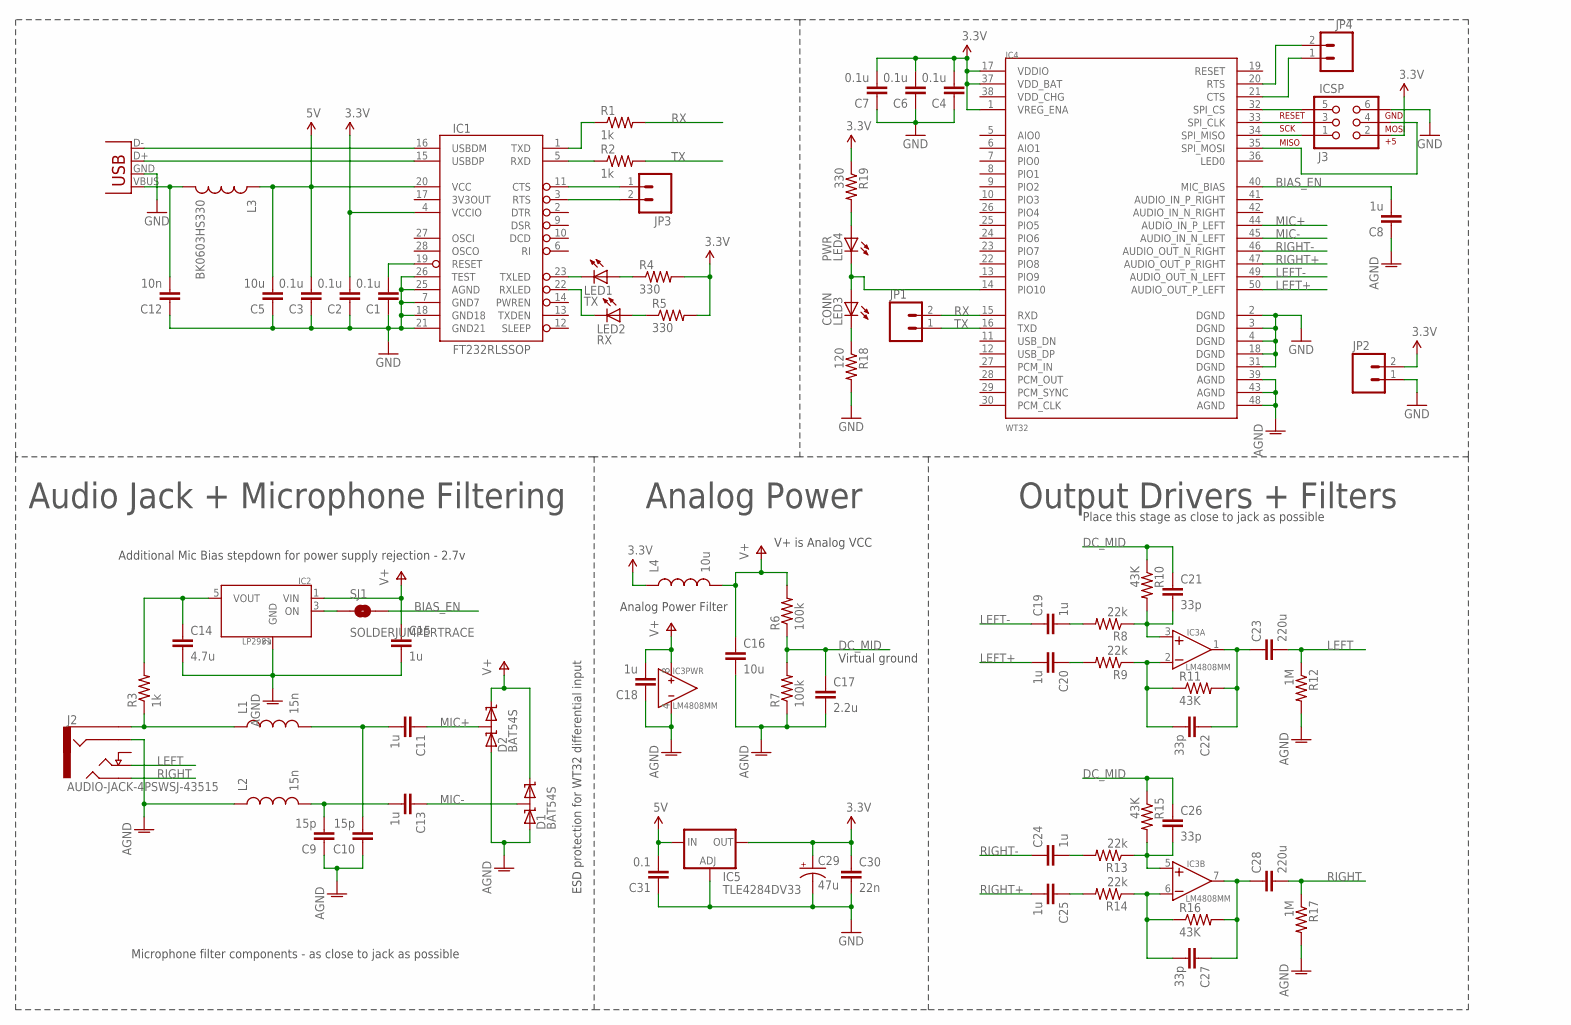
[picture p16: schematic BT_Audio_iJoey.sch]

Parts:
C1, C2, C3, C4, C6, C7: 0.1u; 0603-CAP
C5: 10u; 0805
C8, C11, C13, C15, C18, C19, C20, C24, C25: 1u; 0603-CAP
C9, C10: 15p; 0603-CAP
C12: 10n; 0603-CAP
C14: 4.7u; 0603-CAP
C16: 10u; 0603-CAP
C17: 2.2u; 0603-CAP
C21, C22, C26, C27: 33p; 0603-CAP
C23, C28: 220u; 1210
C29: 47u; PANASONIC_D
C30: 22n; 0603-CAP
C31: 0.1; 0603-CAP
D1, D2: BAT54S; SOT23
IC1: FT232RLSSOP; SSOP28DB
IC2: LP2981; SOT23-5
IC3: LM4808MM; SO8
IC4: WT32
IC5: TLE4284DV33; V-REG_DPACK
J1: USB-A-H
J2: AUDIO-JACK-4PSWSJ-43515; SJ-4351X
J3: ICSP; 2X3
JP1, JP2, JP3, JP4: M02PTH; 1X02
L1, L2: 15n; 0603
L3: BK0603HS330; 0603
L4: 10u; 0603
LED1: TX; LED-0603
LED2: RX; LED-0603
LED3: CONN; LED-0603
LED4: PWR; LED-0603
R1, R2, R3: 1k; 0603-RES
R4, R5, R19: 330; 0603-RES
R6, R7: 100k; 0603-RES
R8, R9, R13, R14: 22k; 0603-RES
R10, R11, R15, R16: 43K; 0603-RES
R12, R17: 1M; 0603-RES
R18: 120; 0603-RES
SJ1: SOLDERJUMPERTRACE; SJ_2S-TRACE

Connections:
3.3V: C2.2, C4.2, C6.2, C7.2, C29.+, C30.1, IC1.4 (VCCIO), IC4.1 (VREG_ENA), IC4.17 (VDDIO), IC4.37 (VDD_BAT), IC5.4 (OUT), J3.2, JP2.2, L4.1, R4.2, R5.2, R19.1
5V: C3.2, C5.2, C31.2, IC1.20 (VCC), IC5.3 (IN), L3.1
AGND: C8.1, C9.1, C10.1, C14.2, C15.2, C16.2, C17.2, C18.1, D1.1 (AN), D2.1 (AN), IC2.2 (GND), IC3.4 (-V), IC4.39 (AGND), IC4.43 (AGND), IC4.48 (AGND), J2.4 (RING2), L2.1, R7.1, R12.2, R17.2
BIAS: C14.1, IC2.5 (VOUT), R3.2
BIAS_EN: C8.2, IC4.40 (MIC_BIAS), SJ1.2
DC_MID: C17.1, C21.1, C26.1, R6.1, R7.2, R10.1, R15.1
GND: C1.1, C2.1, C3.1, C4.1, C5.1, C6.1, C7.1, C12.1, C29.-, C30.2, C31.1, IC1.7 (GND7), IC1.18 (GND18), IC1.21 (GND21), IC1.25 (AGND), IC1.26 (TEST), IC4.2 (DGND), IC4.3 (DGND), IC4.4 (DGND), IC4.18 (DGND), IC4.31 (DGND), IC5.1 (ADJ), J1.GND (VBUS), J3.6, JP2.1, R18.2
LEFT: C23.2, J2.2 (TIP), R12.1
LEFT+: C20.2, IC4.50 (AUDIO_OUT_P_LEFT)
LEFT-: C19.1, IC4.49 (AUDIO_OUT_N_LEFT)
MIC+: C11.1, D2.3 (COM), IC4.44 (AUDIO_IN_P_LEFT)
MIC-: C13.1, D1.3 (COM), IC4.45 (AUDIO_IN_N_LEFT)
unnamed: IC1.15 (USBDP), J1.D+ (D-)
unnamed: IC1.16 (USBDM), J1.D- (D+)
unnamed: IC4.33 (SPI_CLK), J3.3
unnamed: C1.2, IC1.19 (RESET)
unnamed: C12.2, J1.VBUS (GND), L3.2
unnamed: IC4.32 (SPI_CS), J3.5
unnamed: IC1.5 (RXD), R2.1
unnamed: IC1.1 (TXD), R1.1
unnamed: IC4.34 (SPI_MISO), J3.1
unnamed: IC1.23 (TXLED), LED1.C
unnamed: IC1.22 (RXLED), LED2.C
unnamed: LED2.A, R5.1
unnamed: LED1.A, R4.1
unnamed: IC4.35 (SPI_MOSI), J3.4
unnamed: C9.2, C13.2, L2.2
unnamed: J2.1 (SLEEVE), L1.1, R3.1
unnamed: C10.2, C11.2, L1.2
unnamed: C22.2, IC3.2 (-), R9.1, R11.1
unnamed: C20.1, R9.2
unnamed: C21.2, IC3.3 (+), R8.1, R10.2
unnamed: C19.2, R8.2
unnamed: C22.1, C23.1, IC3.1 (O), R11.2
unnamed: C27.2, IC3.6 (-), R14.1, R16.1
unnamed: C25.1, R14.2
unnamed: C26.2, IC3.5 (+), R13.1, R15.2
unnamed: C24.2, R13.2
unnamed: C27.1, C28.1, IC3.7 (O), R16.2
unnamed: IC2.3 (ON), SJ1.1
unnamed: IC1.11 (CTS), JP3.1
unnamed: IC1.3 (RTS), JP3.2
unnamed: IC4.21 (CTS), JP4.1
unnamed: IC4.20 (RTS), JP4.2
unnamed: IC4.14 (PIO10), LED3.A, LED4.C
unnamed: LED3.C, R18.1
unnamed: LED4.A, R19.2
RIGHT: C28.2, J2.3 (RING1), R17.1
RIGHT+: C25.2, IC4.47 (AUDIO_OUT_P_RIGHT)
RIGHT-: C24.1, IC4.46 (AUDIO_OUT_N_RIGHT)
RX: IC4.15 (RXD), JP1.2, R1.2
TX: IC4.16 (TXD), JP1.1, R2.2
V+: C15.1, C16.1, C18.2, D1.2 (CAT), D2.2 (CAT), IC2.1 (VIN), IC3.8 (+V), L4.2, R6.2

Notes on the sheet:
Place this stage as close to jack as possible
Analog Power
Audio Jack + Microphone Filtering
Output Drivers + Filters
Microphone filter components - as close to jack as possible
Additional Mic Bias stepdown for power supply rejection - 2.7v
Virtual ground
Analog Power Filter
V+ is Analog VCC
ESD protection for WT32 differential input

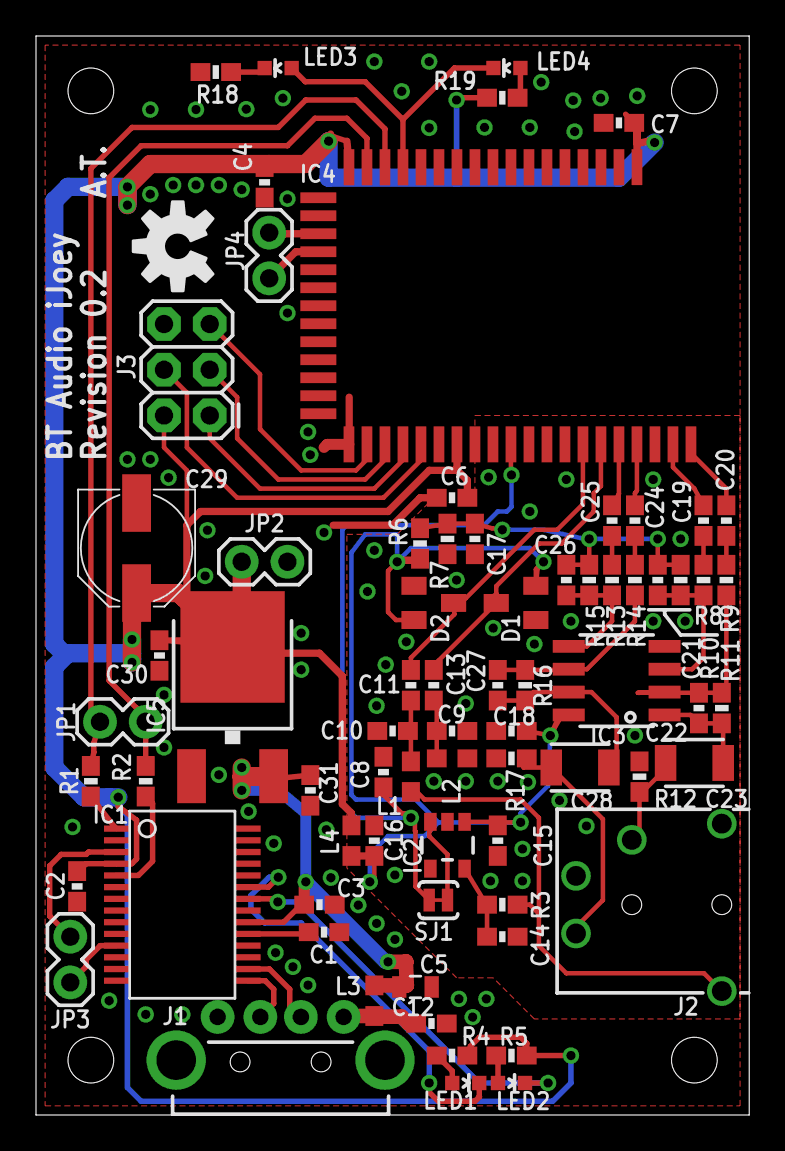
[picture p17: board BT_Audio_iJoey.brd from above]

Board: 2 copper layers, 39.6 x 59.9 mm, 76 parts (0 on the bottom side), 53 nets.

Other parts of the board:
DRILEGEND: DRILEGEND
U$1: A5L-LOC
U$2: OSHW-LOGO-M

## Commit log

2013-04-19 Initial commit.
    [BT_Audio_iJoey.brd, BT_Audio_iJoey.dxf, BT_Audio_iJoey.sch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]
2013-09-18 Add verification tests as plain text.
    [DESIGN_CRITERIA.xls]

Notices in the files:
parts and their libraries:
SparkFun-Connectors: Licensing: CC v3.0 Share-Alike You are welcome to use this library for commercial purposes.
